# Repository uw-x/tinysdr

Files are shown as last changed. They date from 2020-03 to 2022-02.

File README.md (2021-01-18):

## Overview
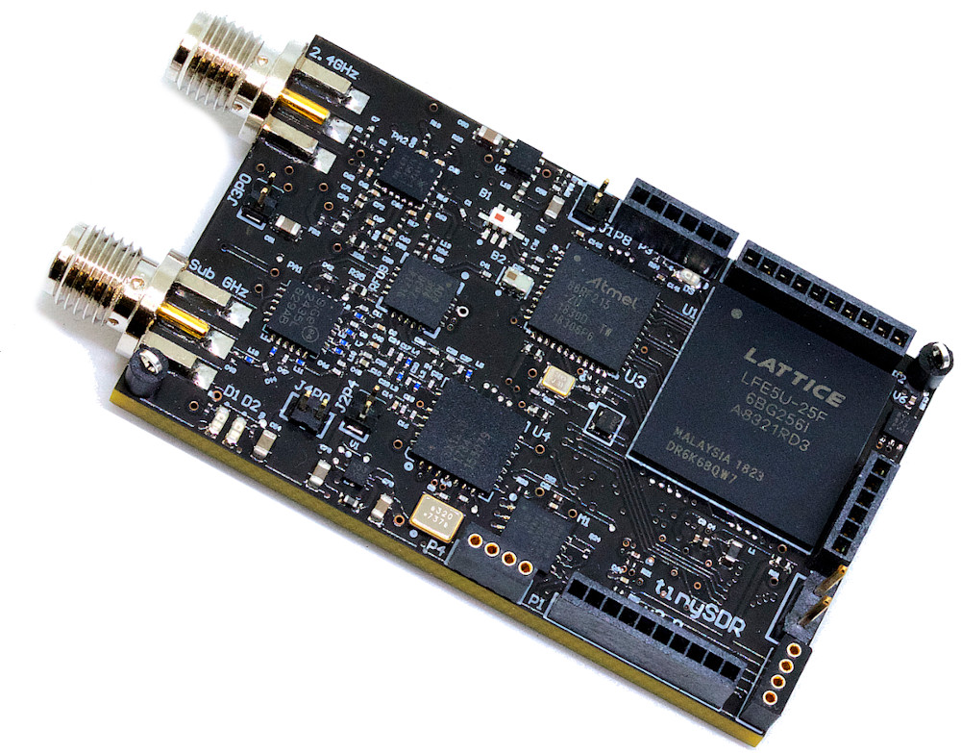
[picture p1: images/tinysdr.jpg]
TinySDR Board


TinySDR is the first software-defined radio platform specialized for internet-of-things networks.

### Hardware
TinySDR schematic is in [hardware](hardware/schematic.pdf). You can download [PCB design files](hardware/pcb-tinysdr.zip) to build TinySDR hardware.

### Firmware
TinySDR firmware CCS project is in [firmware](firmware/).

### FPGA Demos
TinySDR Bluetooth beacons and LoRa demos are in [demo](demo/).
- [LoRa Modulator](https://github.com/uw-x/lora-modulator)
- [FSK Modulator](https://github.com/mehrdadh/fsk-modulator)

### Contributers
  - [Mehrdad Hessar](https://github.com/mehrdadh)
  - [Ali Najafi](https://github.com/anajafi)
  - [Vikram Iyer](https://github.com/viyer)

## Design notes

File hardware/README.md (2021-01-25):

# Overview
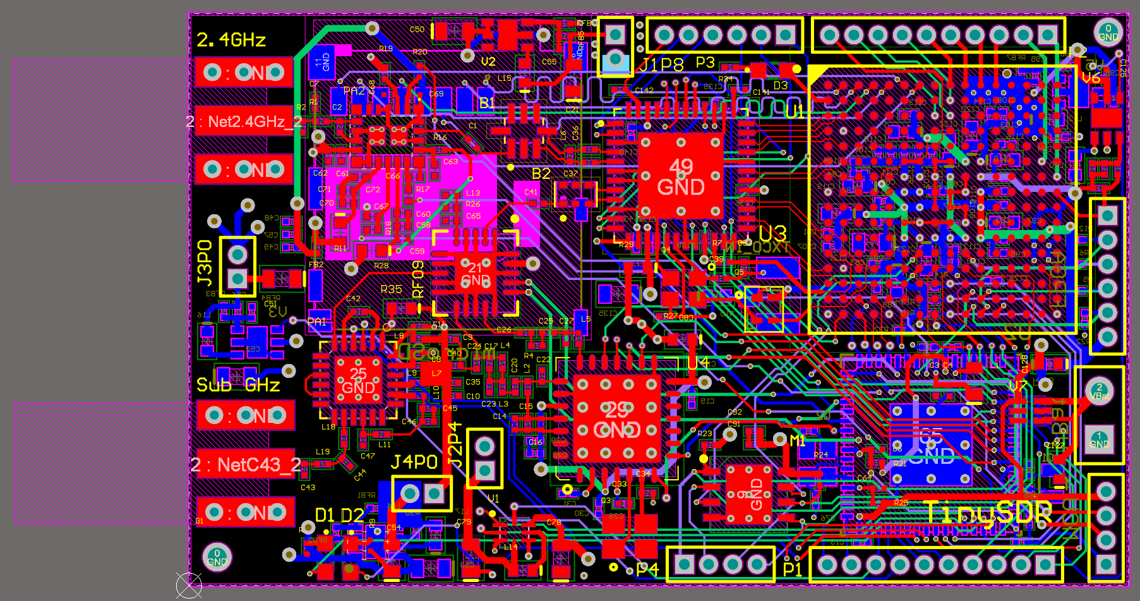
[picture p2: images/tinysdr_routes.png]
TinySDR PCB All Layers


TinySDR hardware designed with a six layers FR4 PCB material. We need six layer to implement multiple components with complex power plains that gives us flexibility to control power consumption in various scenarios.

We place RF paths on the top layer with impedance control for Sub-GHz and 2.4 GHz frequencies.

This PCB is originally designed with Altium Designer version 19 and most recently rendered by version 20.1.11. All the libraries that required to build the PCB are included in [PCB files](./pcb-tinysdr.zip).

## Layers
After routing wires for all components we place polygons on each layer. In table below we show all the polygons and their purpose in our design.

| Layer | Polygons Description |Image  |
| --- | --- |---|
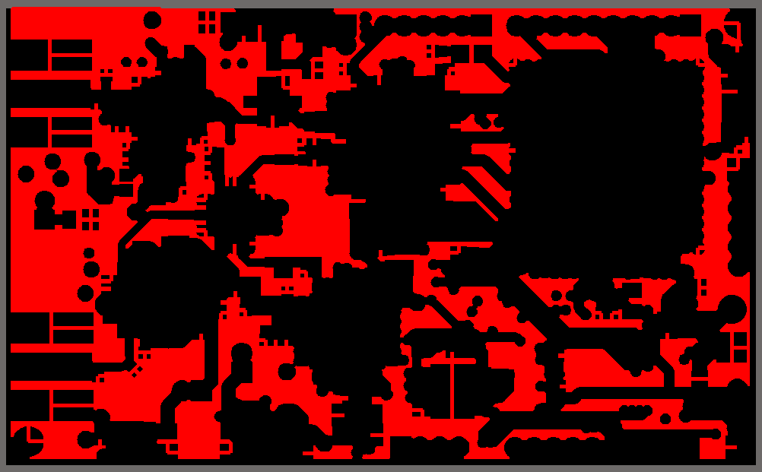
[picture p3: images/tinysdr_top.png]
Top Layer Polygon
| Top | Connected to GND.<br /> Multiple Polygons.<br /> Includes impedance control for both RF paths and LVDS connections. | |
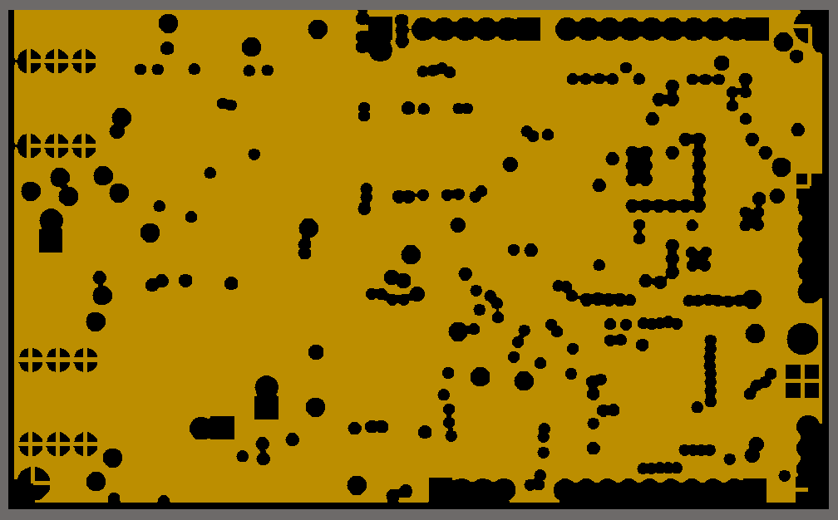
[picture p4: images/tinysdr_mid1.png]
Inner Layer 1 Polygon
| Inner 1 | Connected to GND. | |
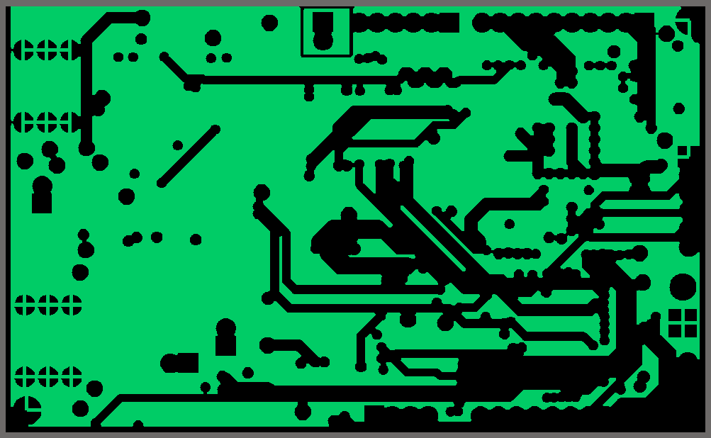
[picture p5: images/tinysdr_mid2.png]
Inner Layer 2 Polygon
| Inner 2 | Connected to GND. | |
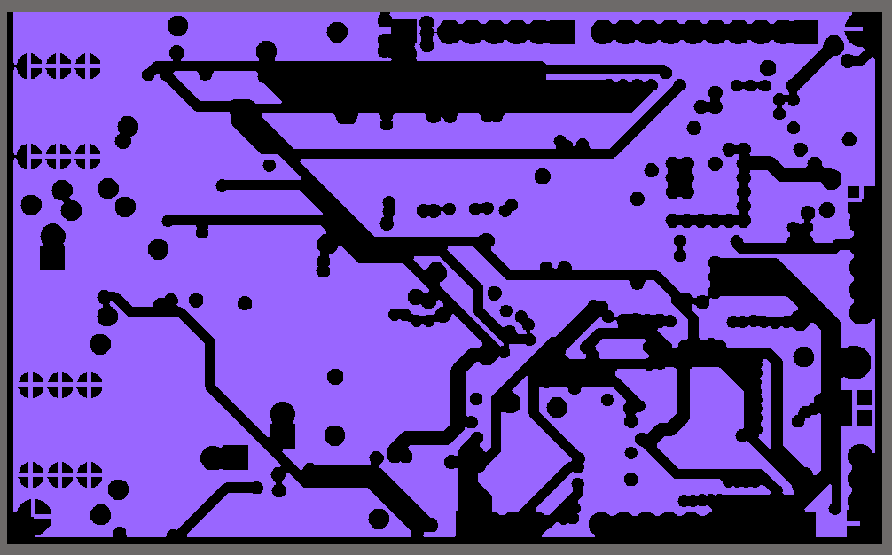
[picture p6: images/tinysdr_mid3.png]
Inner Layer 3 Polygon
| Inner 3 | Connected to GND. | |
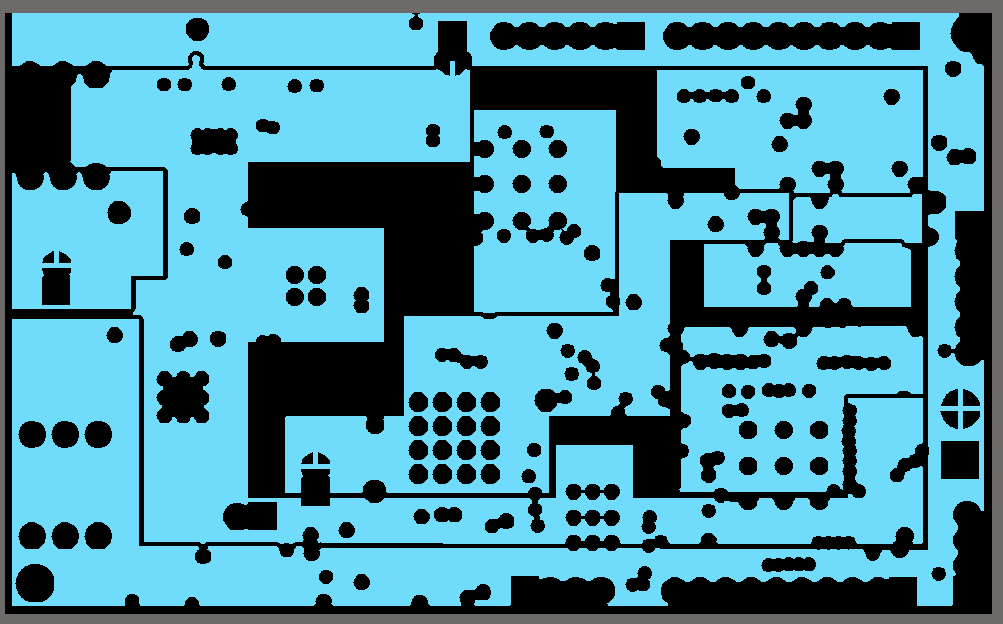
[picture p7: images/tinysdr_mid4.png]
Inner Layer 4 Polygons
| Inner 4 | Connected to Power.<br /> Includes multiple polygons for various power planes. | |
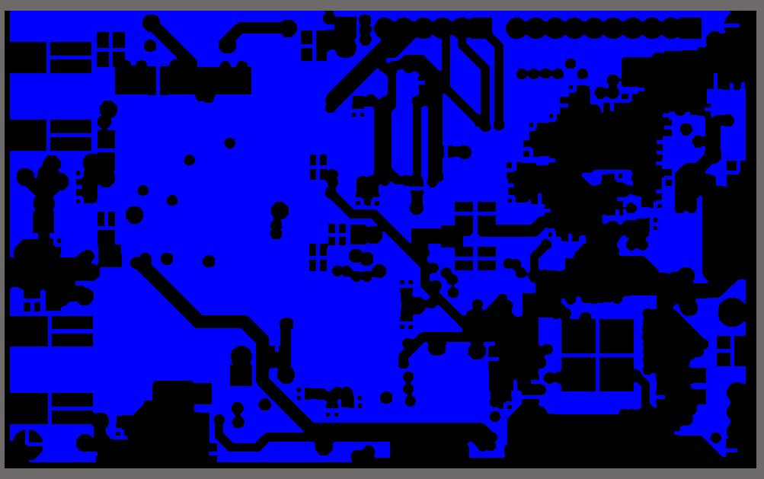
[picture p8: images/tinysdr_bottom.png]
Bottom Layer Polygon
| Bottom | Connected to GND. | |

## How to Use
To use PCB files in this directory follow these steps:
- Install the latest version of the [Altium Designer](https://www.altium.com/products/downloads)
- Download and extract [PCB files](./pcb-tinysdr.zip)
- Open project in Altium Designer

Note: When you run design rule check you will see few erros regarding the `silk gaps` which you can ignore.

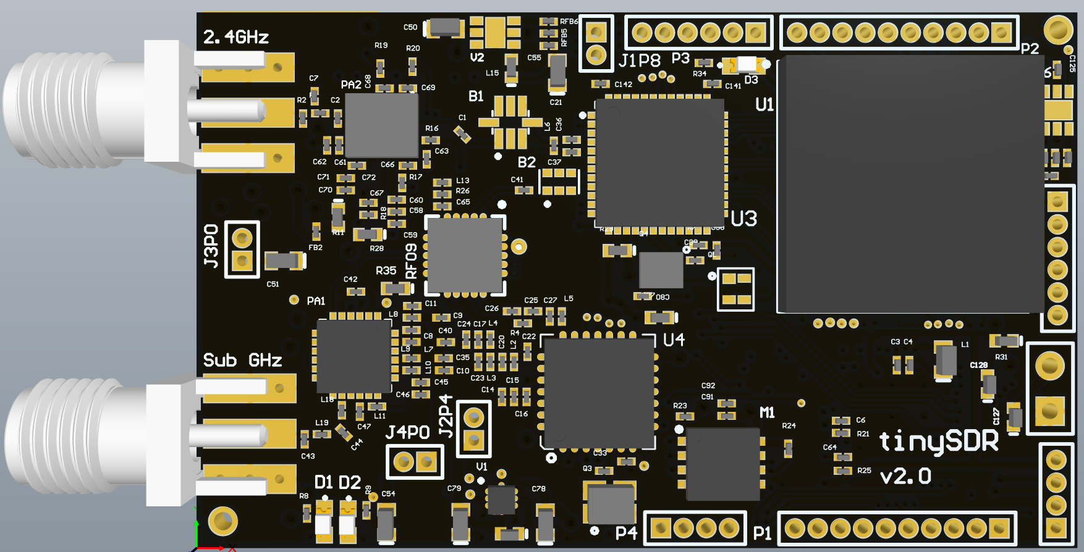
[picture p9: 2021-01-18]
images/tinysdr_3d.png

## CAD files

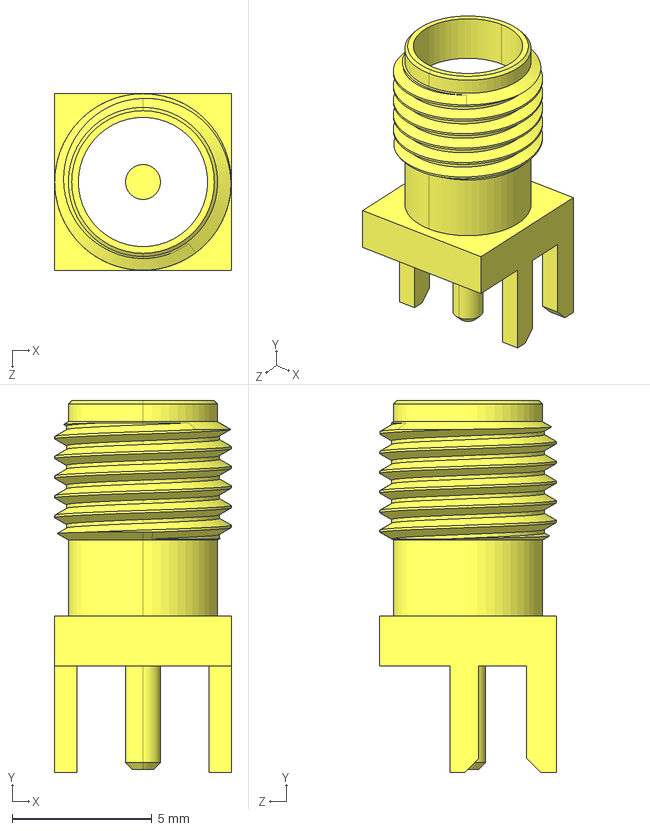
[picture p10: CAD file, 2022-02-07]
hardware/pcb-tinysdr/ALTIUM_EMBEDDED_MODELS/Samtec-SMA-J-P-H-ST-EM1.step
6.35 x 13.3 x 6.35 mm

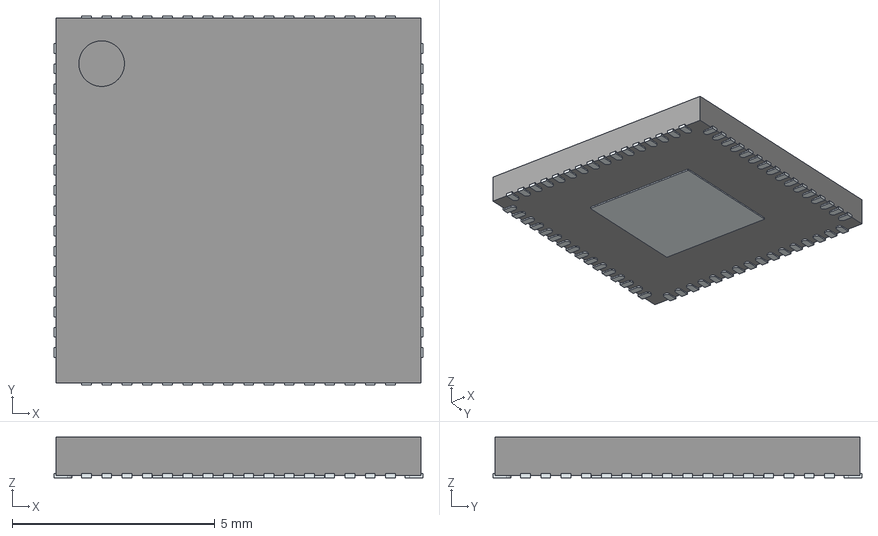
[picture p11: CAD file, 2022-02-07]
hardware/pcb-tinysdr/ALTIUM_EMBEDDED_MODELS/MSP432P401RIRGCR.stp
9.10 x 9.10 x 1.00 mm
ThermalPin
PinsArrayLR
PinsArrayTB

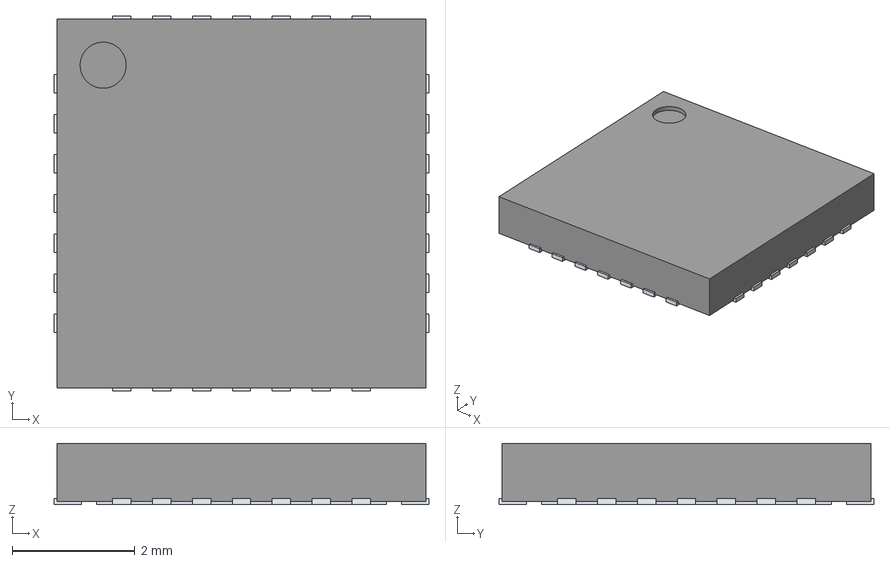
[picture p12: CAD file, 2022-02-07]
hardware/pcb-tinysdr/ALTIUM_EMBEDDED_MODELS/SX1276IMLTRT.stp
6.10 x 6.10 x 1.00 mm
ThermalPin
PinsArrayLR
PinsArrayTB

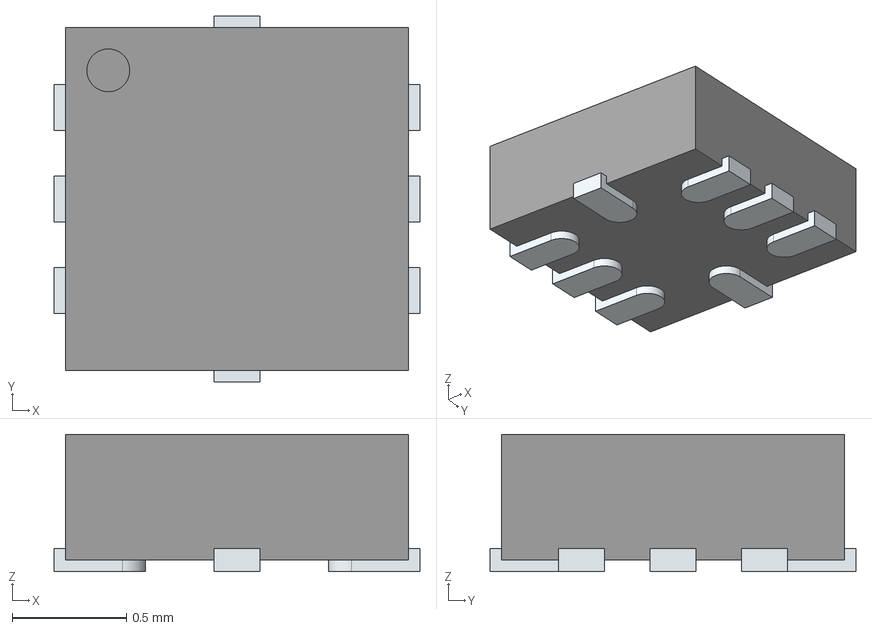
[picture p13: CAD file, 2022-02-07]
hardware/pcb-tinysdr/ALTIUM_EMBEDDED_MODELS/SC560HULTRT.stp
1.60 x 1.60 x 0.6 mm
PinsArrayLR
PinsArrayTB

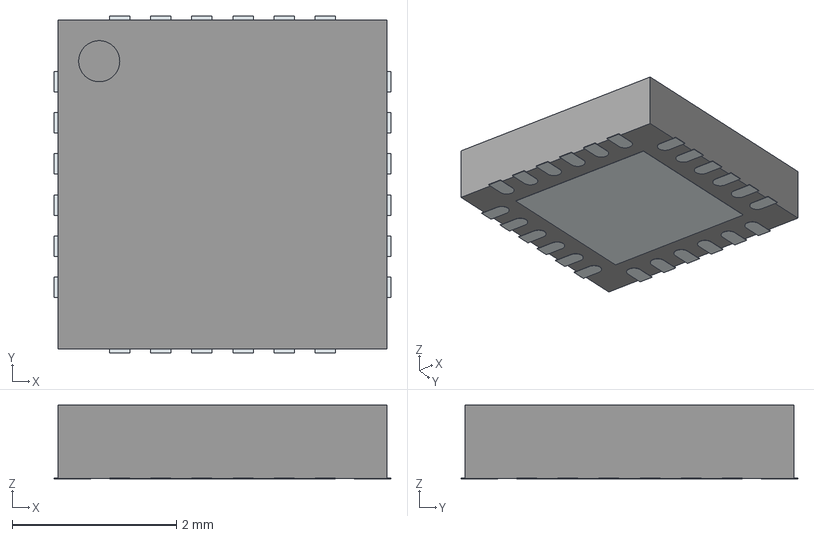
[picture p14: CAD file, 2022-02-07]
hardware/pcb-tinysdr/ALTIUM_EMBEDDED_MODELS/SE2435L-R.stp
4.10 x 4.10 x 0.9 mm
ThermalPin
PinsArrayLR
PinsArrayTB

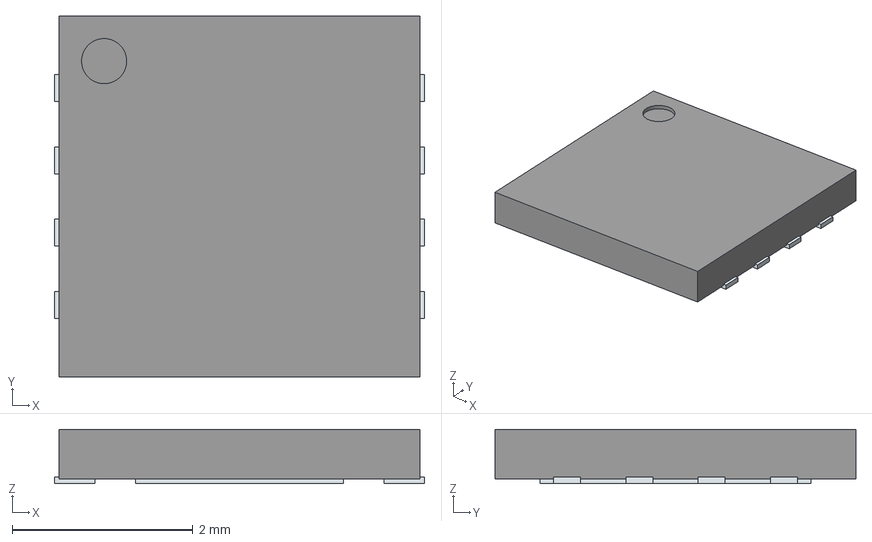
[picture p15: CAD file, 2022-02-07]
hardware/pcb-tinysdr/ALTIUM_EMBEDDED_MODELS/S25FL064LABNFI043.stp
4.10 x 4.00 x 0.6 mm
ThermalPin
PinsArrayLR

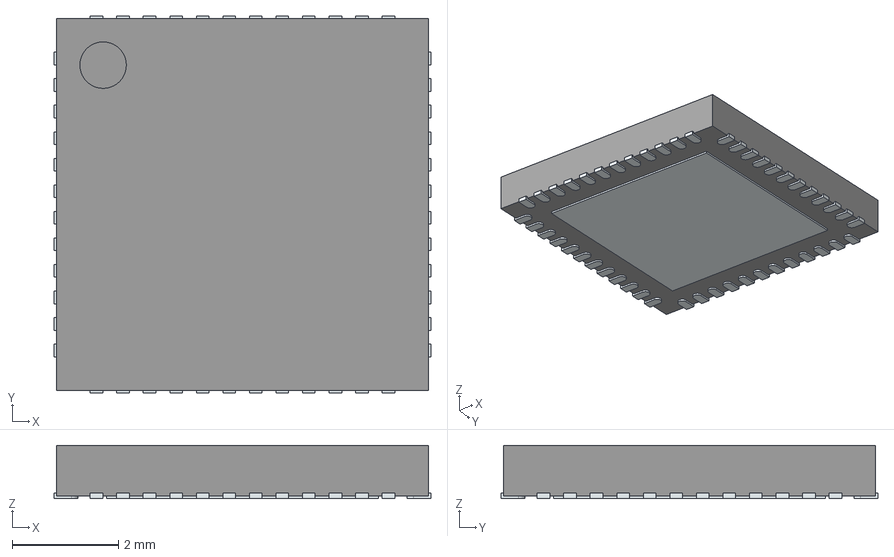
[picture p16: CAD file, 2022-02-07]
hardware/pcb-tinysdr/ALTIUM_EMBEDDED_MODELS/CLT01-38SQ7-TR.stp
7.10 x 7.10 x 1.00 mm
ThermalPin
PinsArrayLR
PinsArrayTB

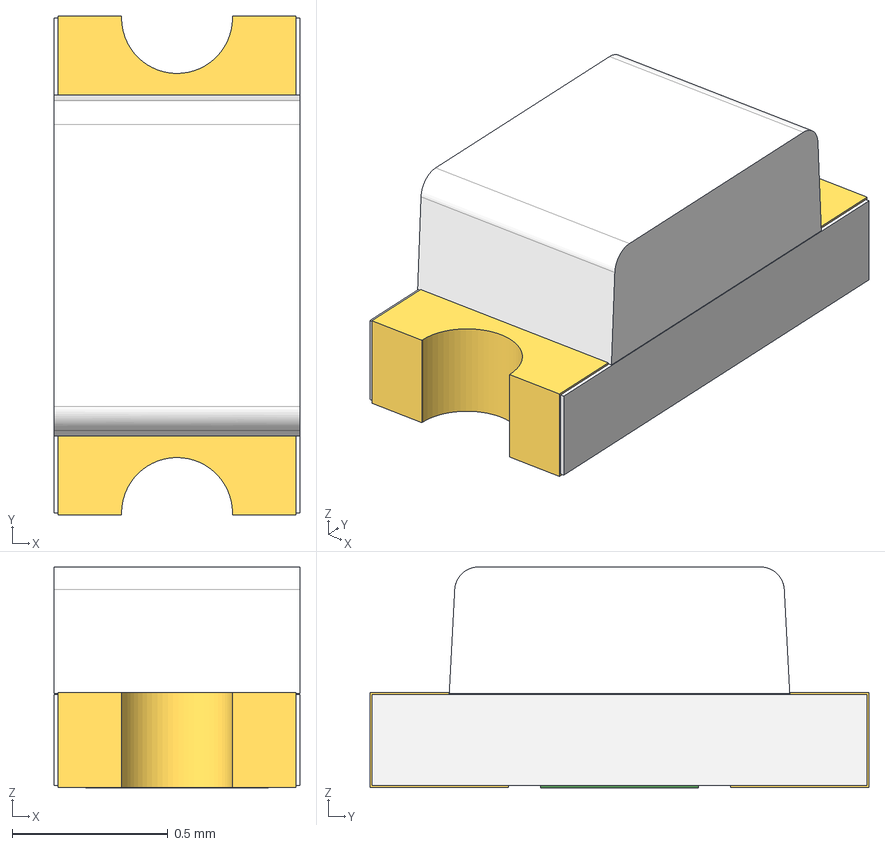
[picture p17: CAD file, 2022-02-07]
hardware/pcb-tinysdr/ALTIUM_EMBEDDED_MODELS/LED 0603 single color.stp
0.787 x 1.60 x 0.709 mm

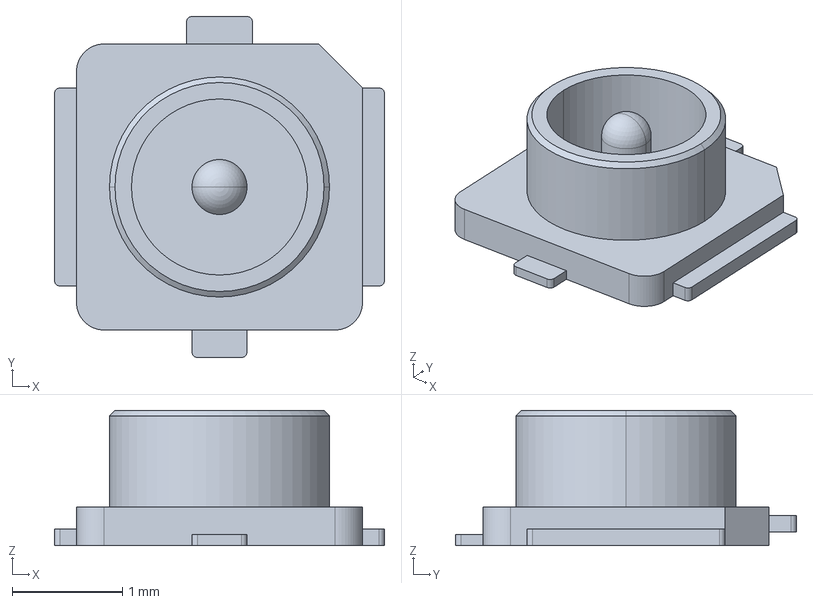
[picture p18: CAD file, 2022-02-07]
hardware/pcb-tinysdr/ALTIUM_EMBEDDED_MODELS/c-1909763-1-b-3d.stp
3.00 x 3.10 x 1.23 mm

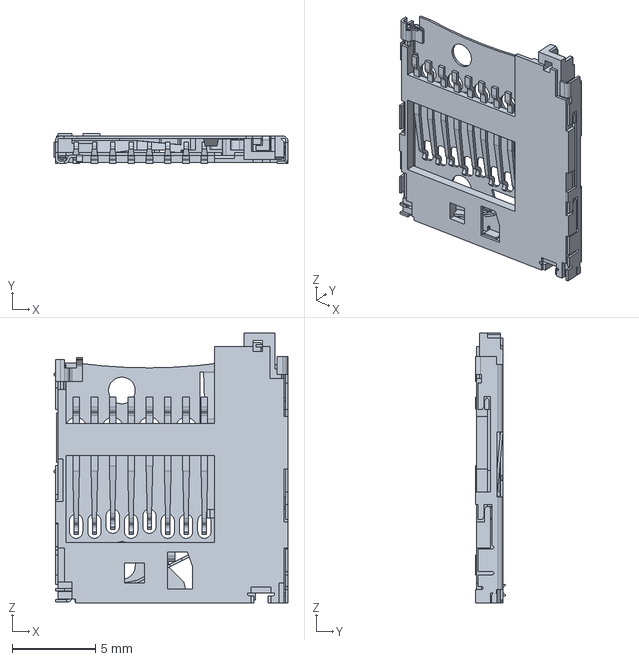
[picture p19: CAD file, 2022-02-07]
hardware/pcb-tinysdr/ALTIUM_EMBEDDED_MODELS/c-2201778-1-a-3d.stp
14.0 x 1.80 x 16.2 mm

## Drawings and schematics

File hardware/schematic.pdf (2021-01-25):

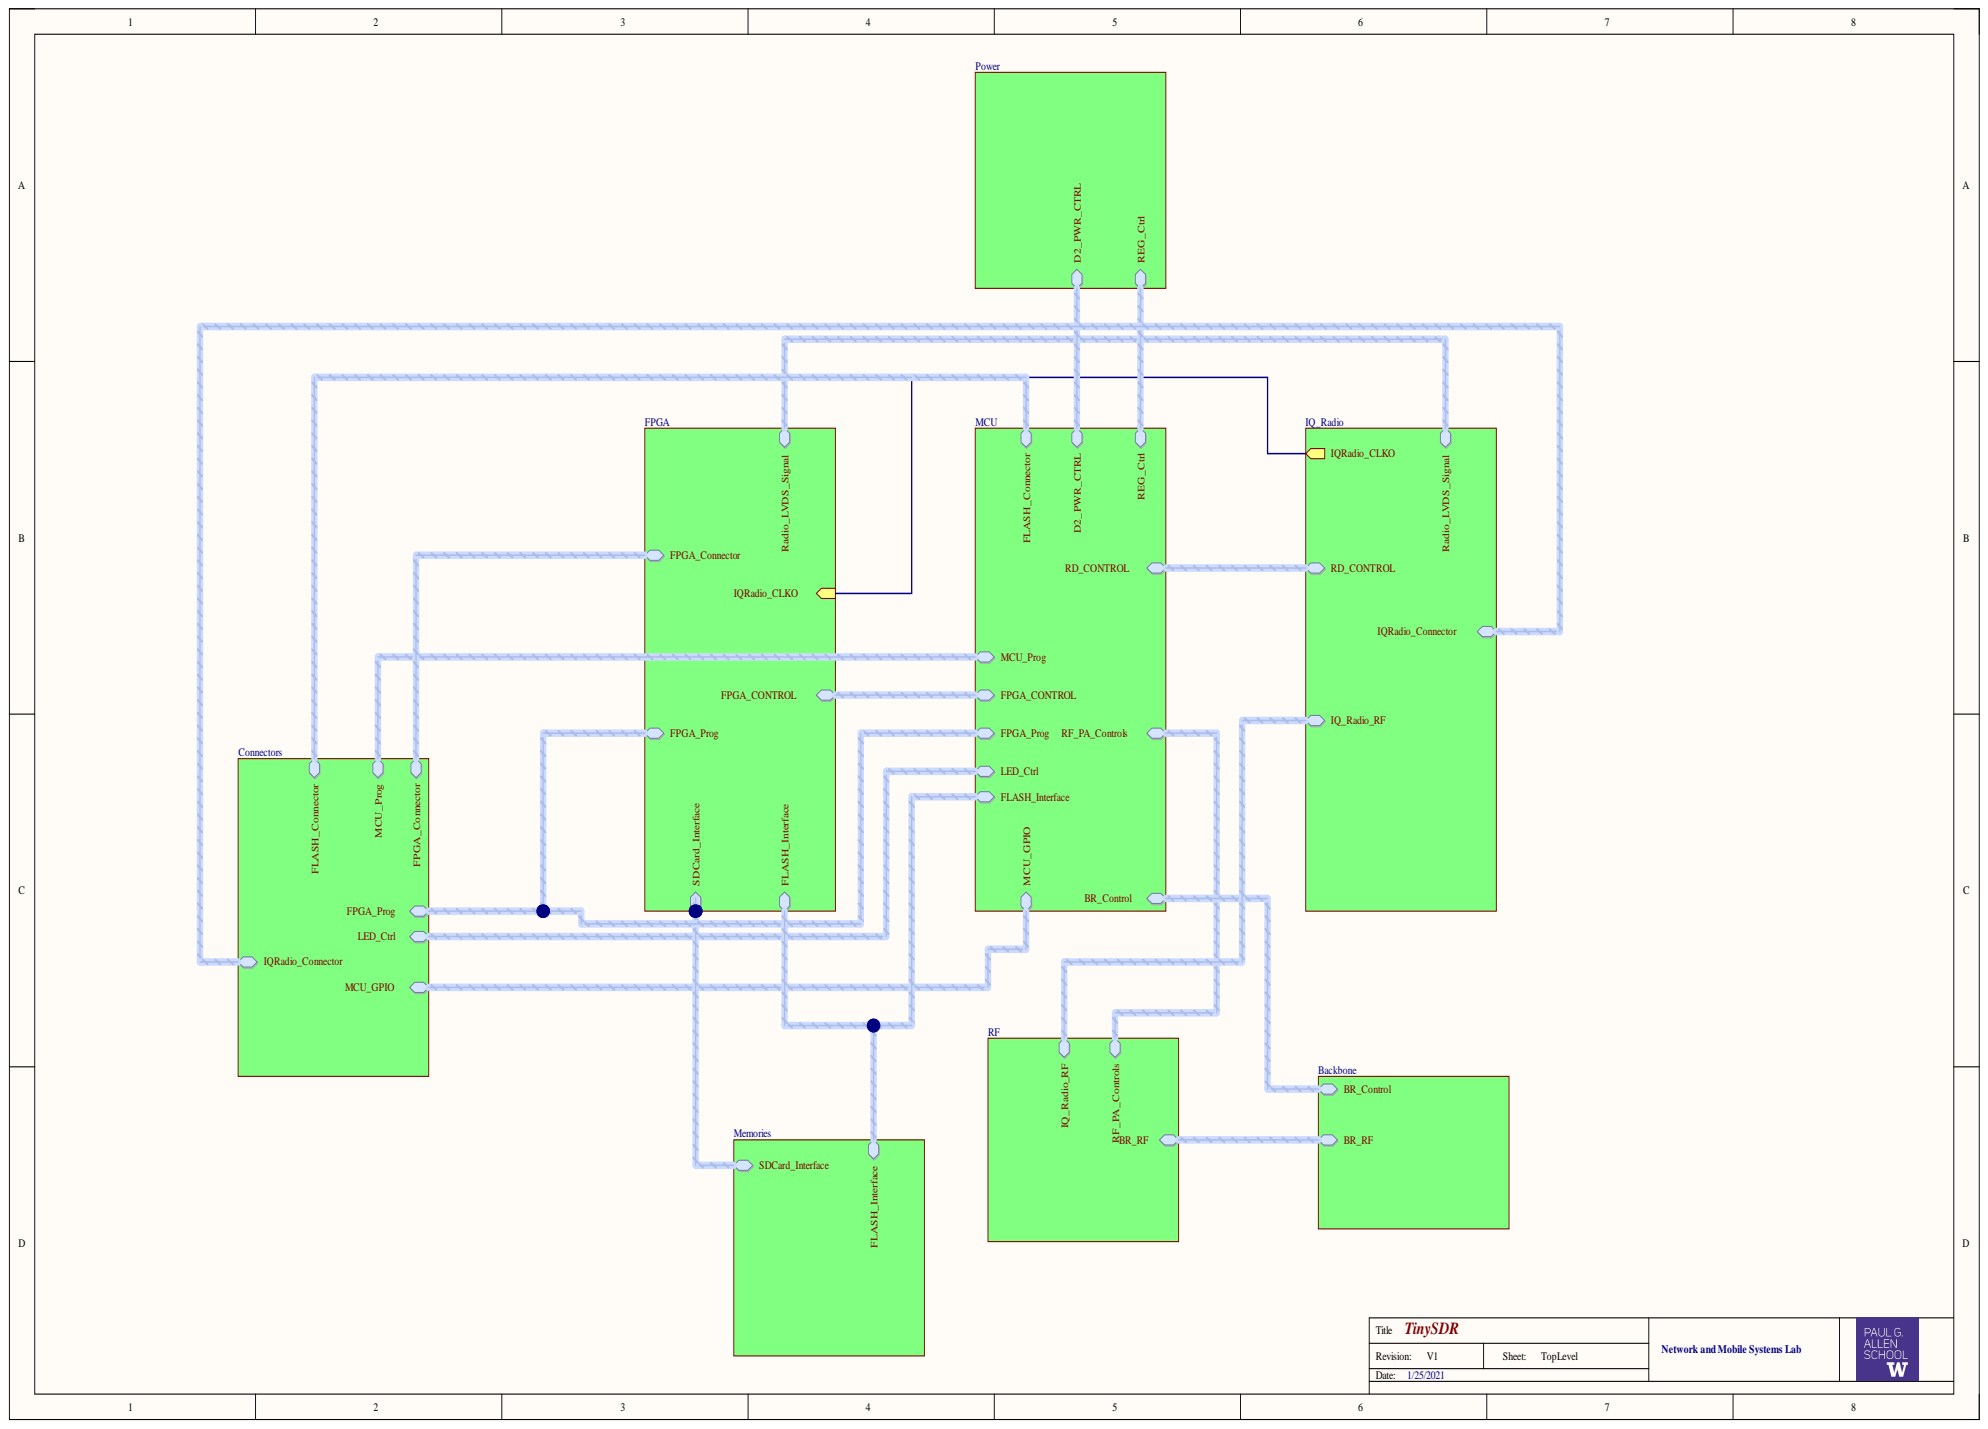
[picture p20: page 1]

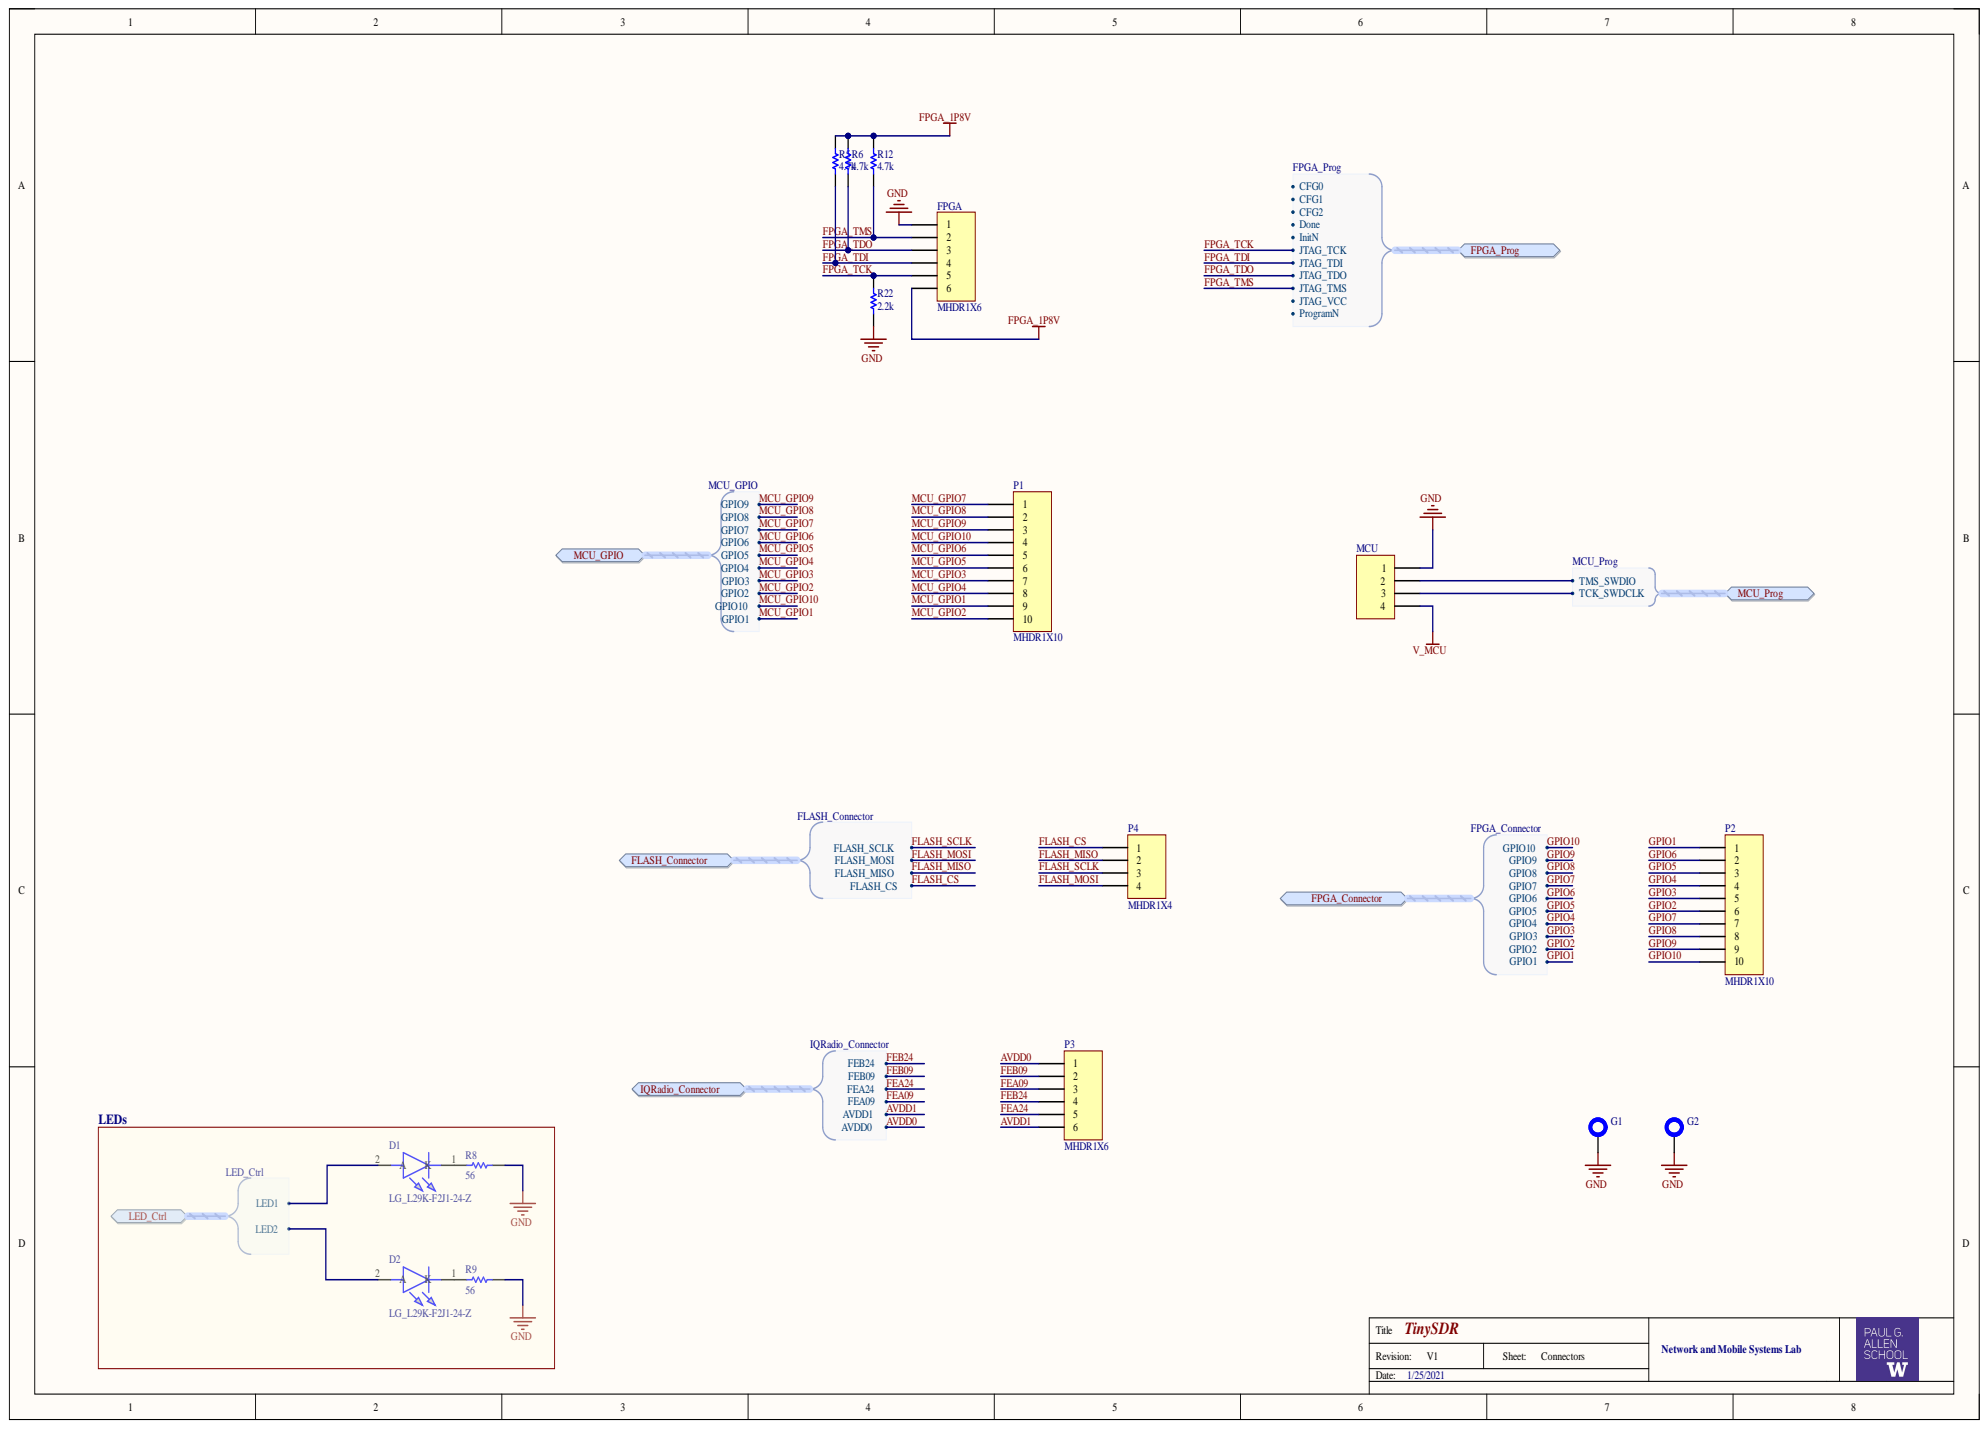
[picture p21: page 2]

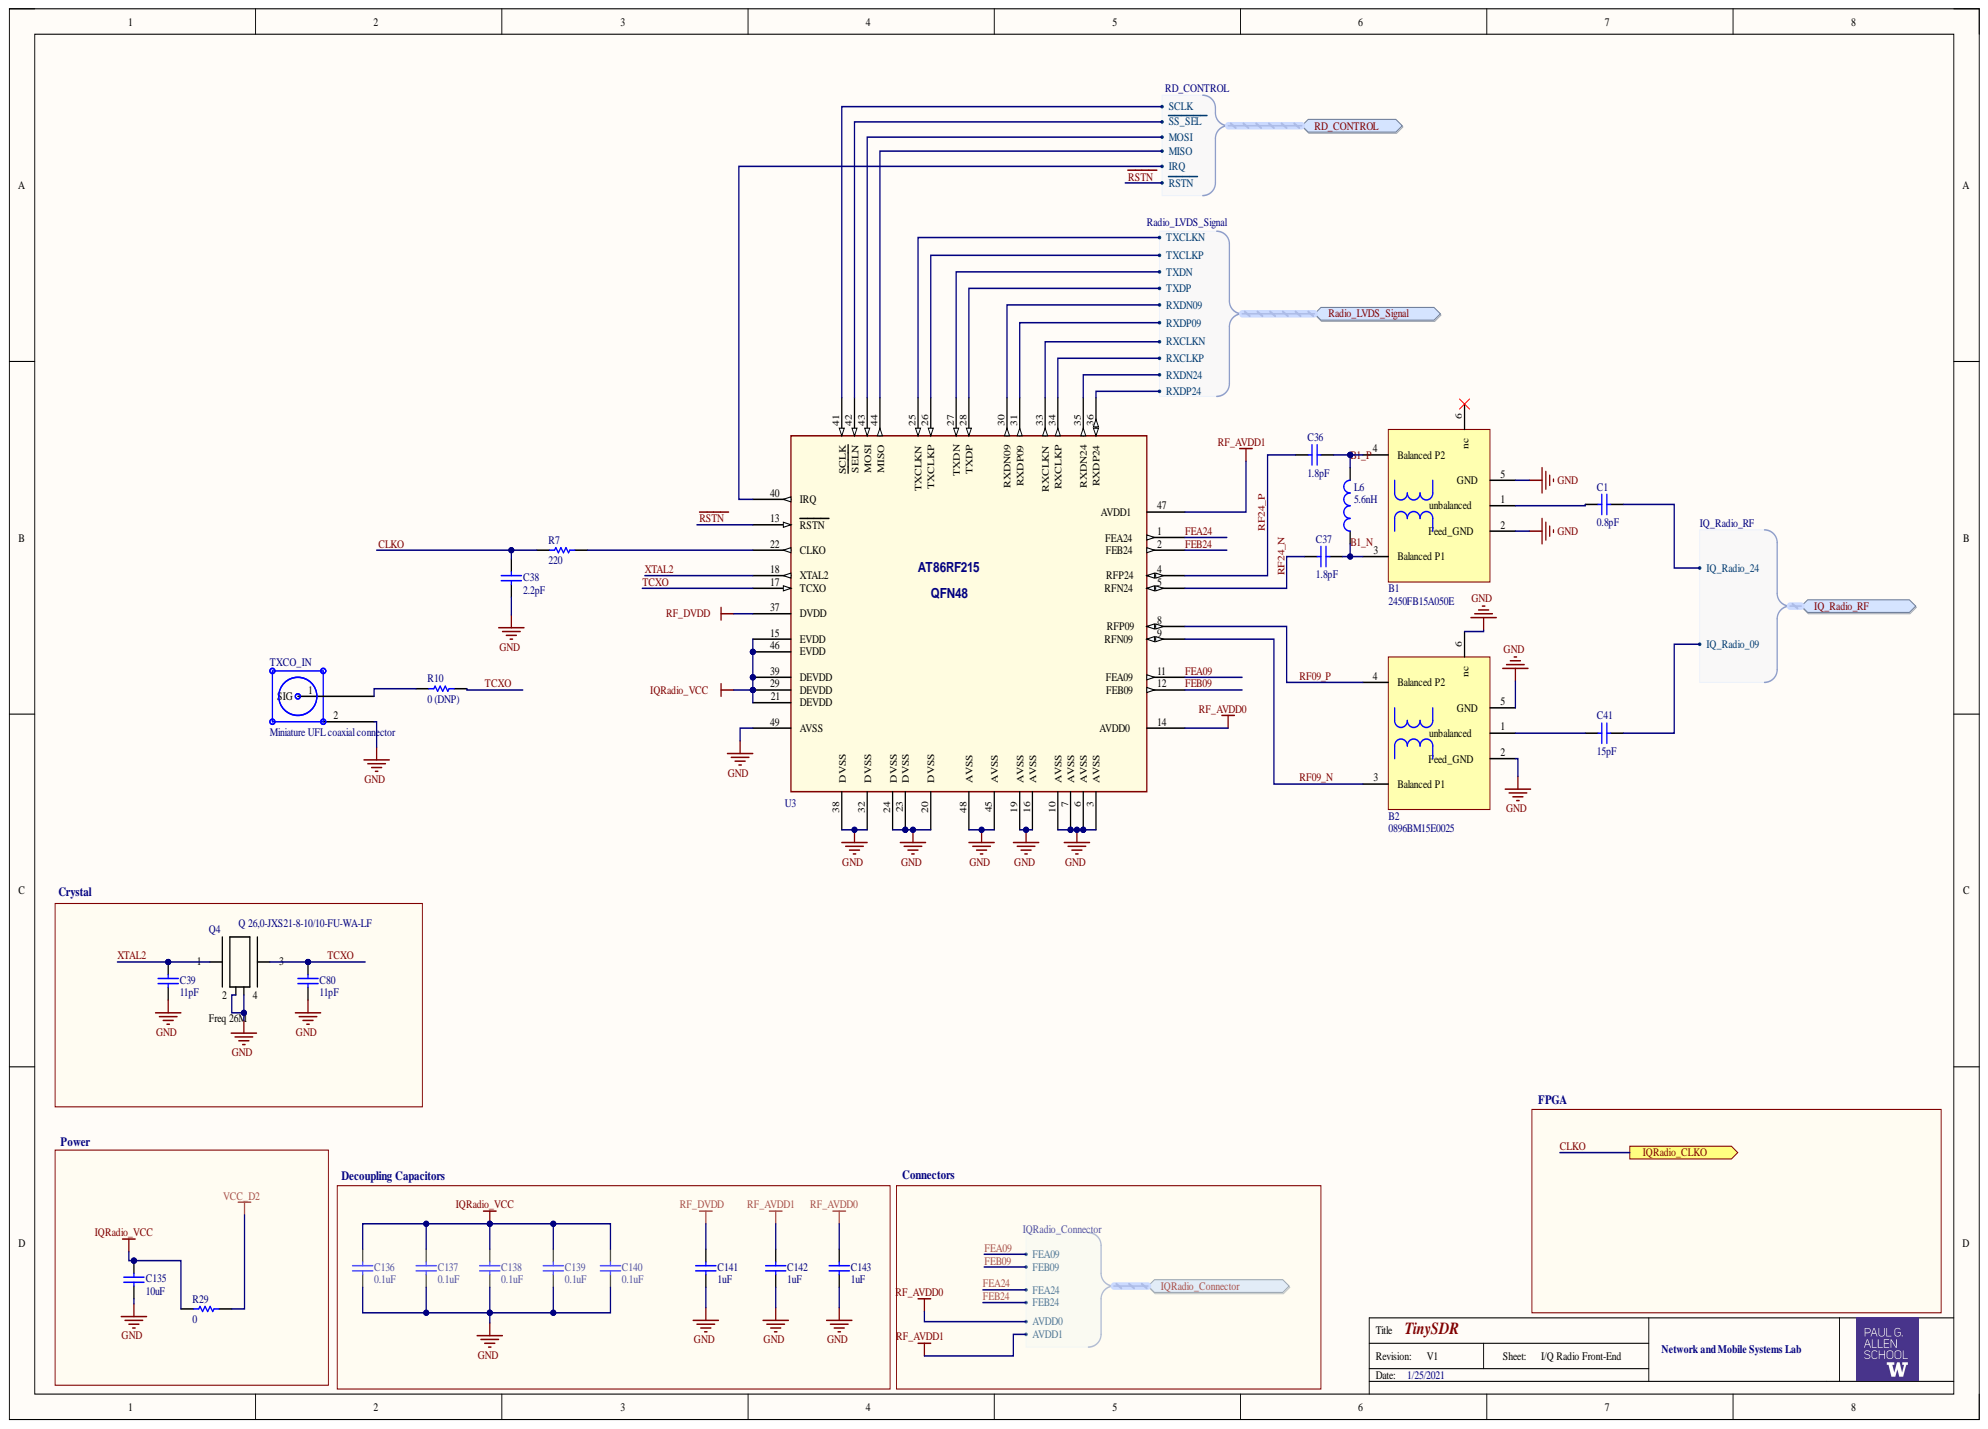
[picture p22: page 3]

Miniature UFL coaxial connector

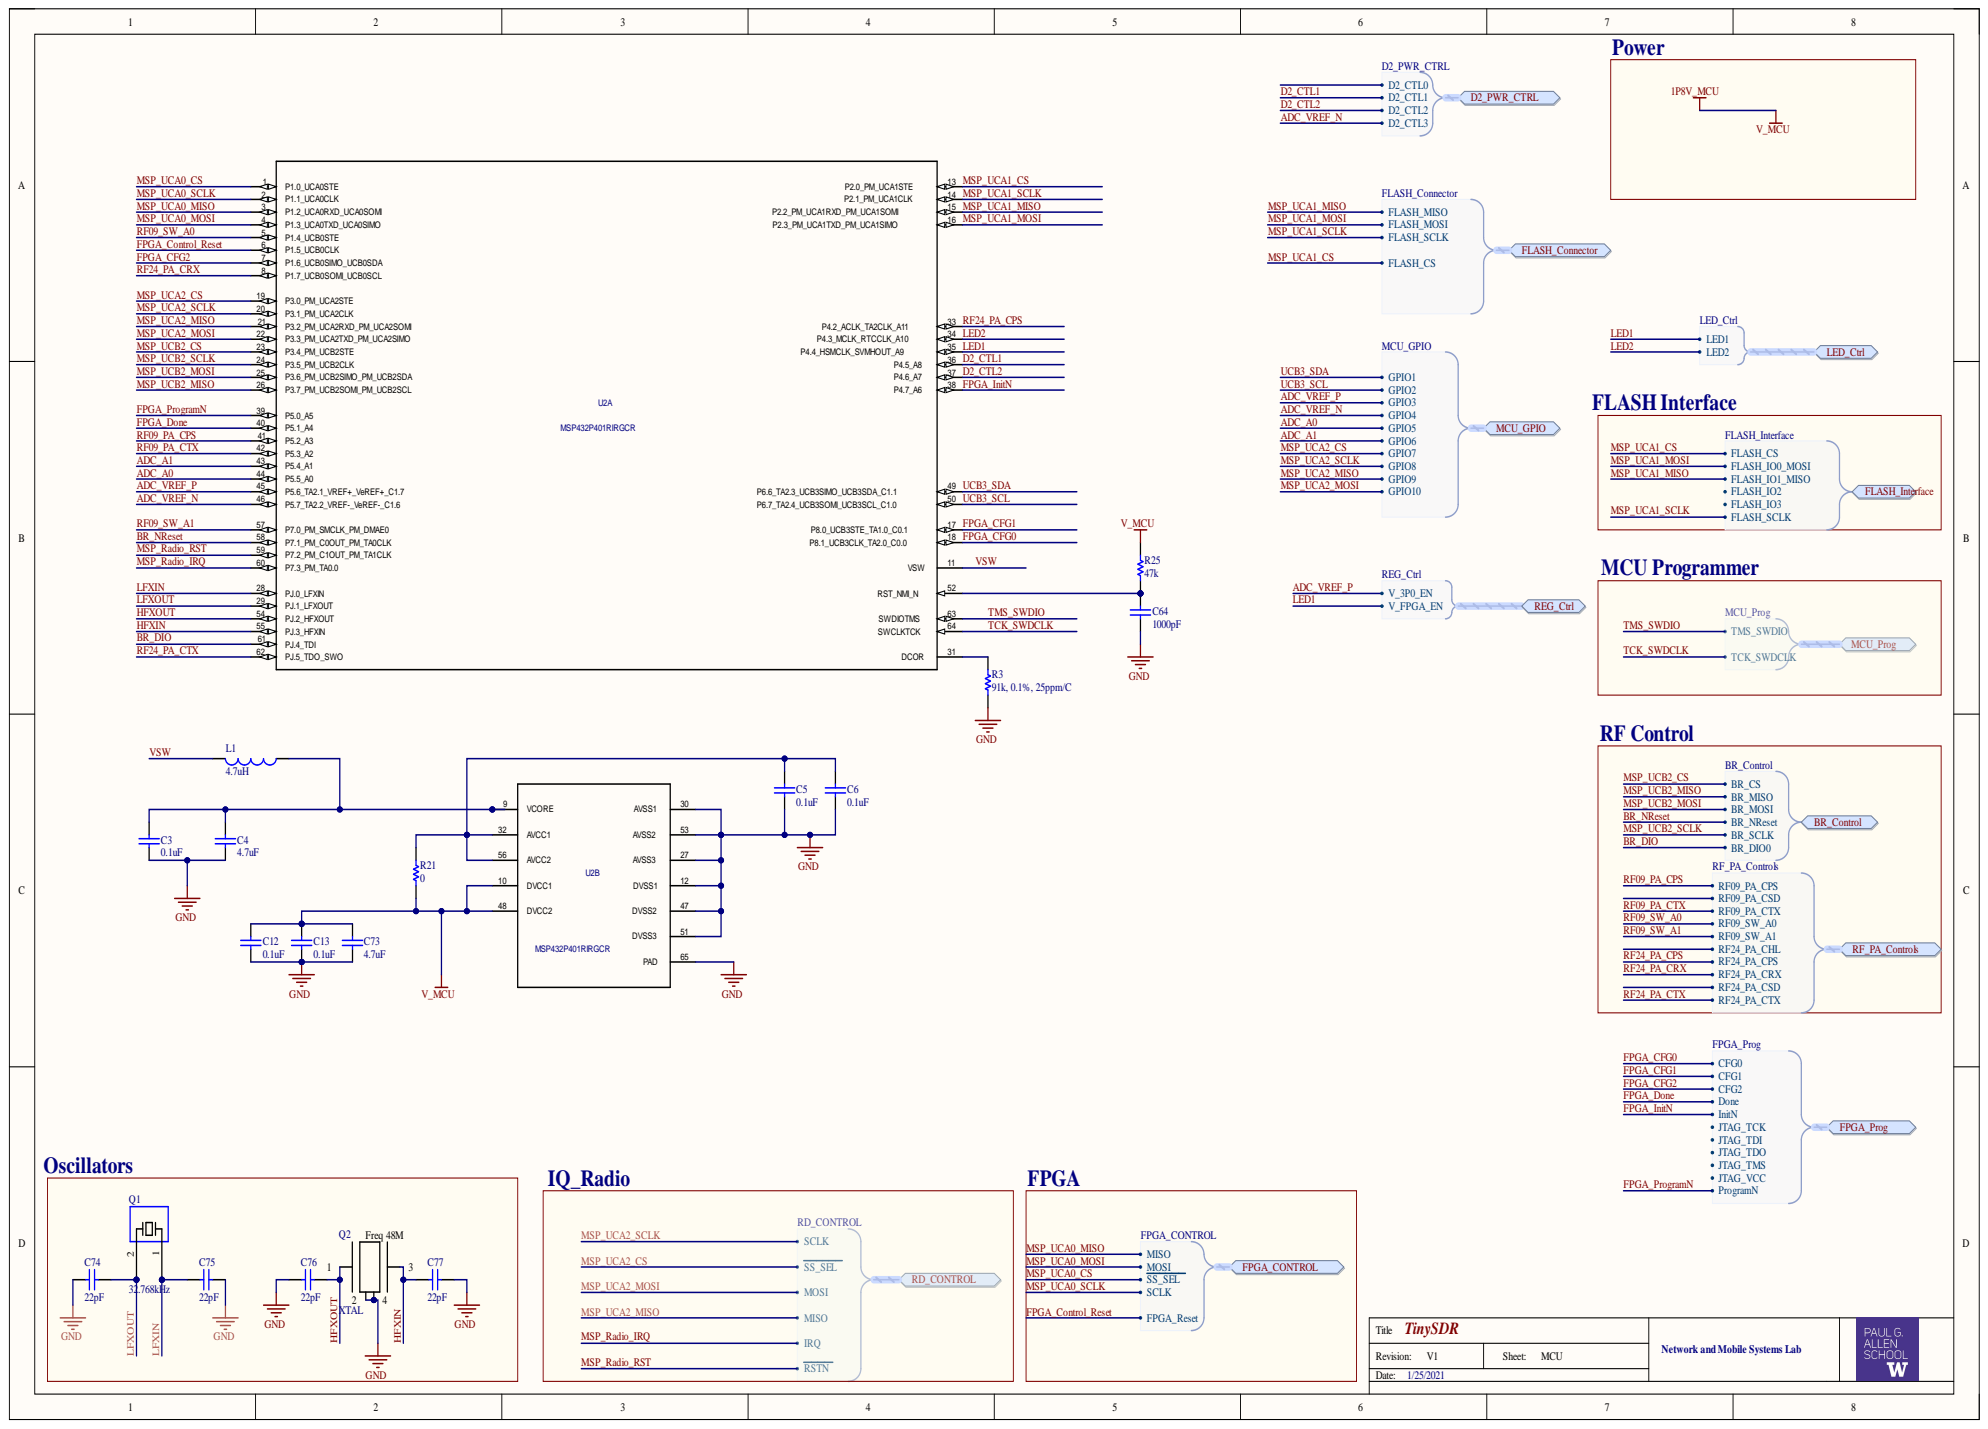
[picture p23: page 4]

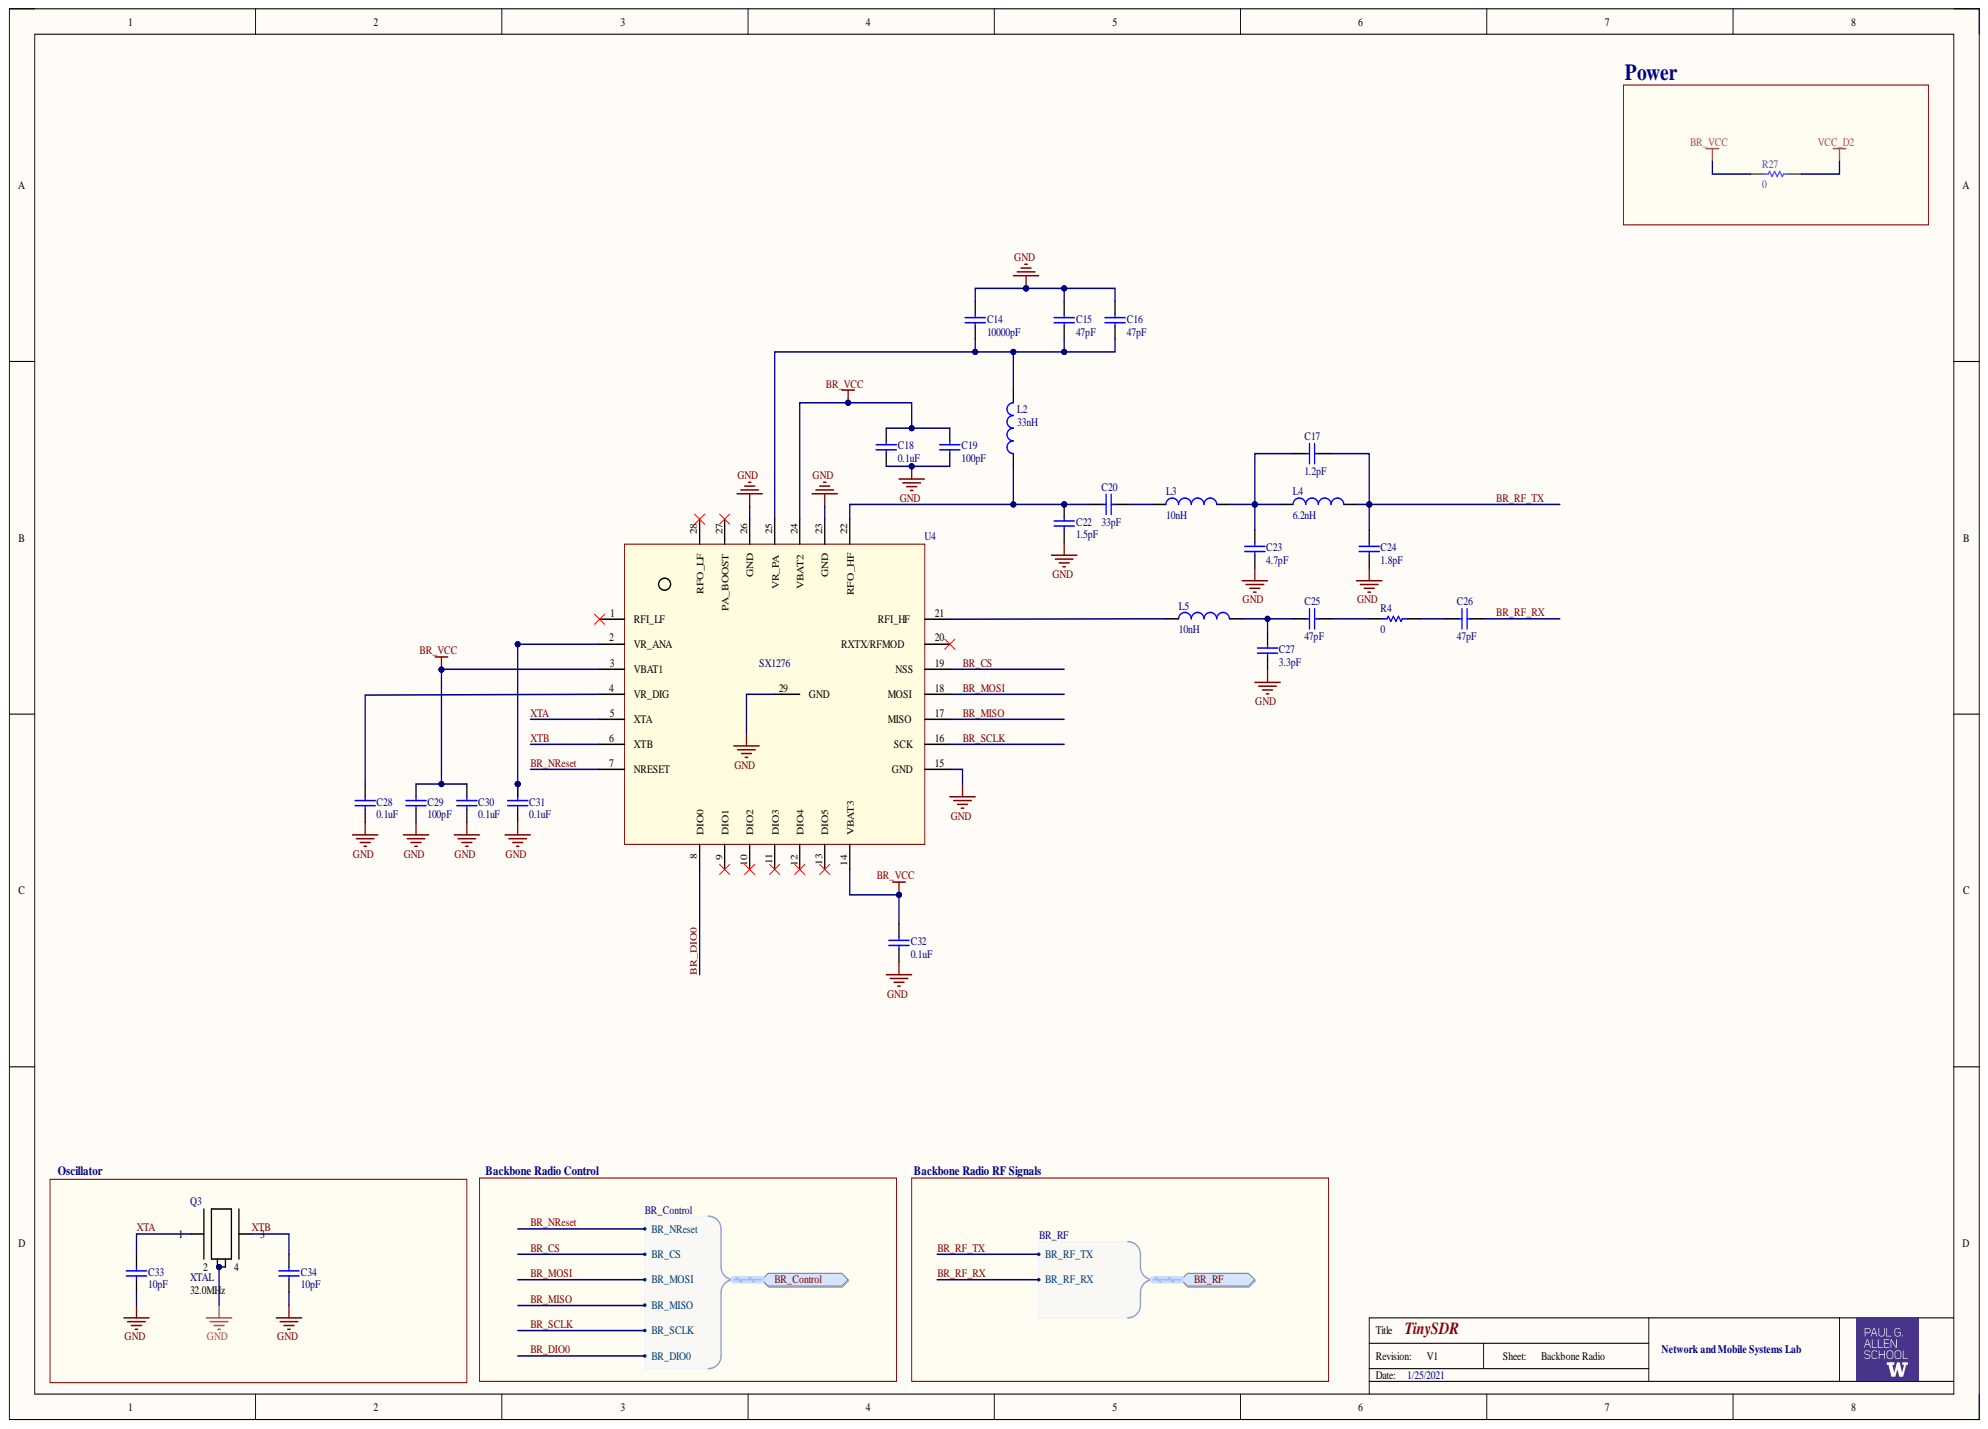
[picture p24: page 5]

VBAT1 3

VR_DIG 4

XTA XTB BR_NReset | | XTA 5 XTB 6 NRESET 7

Backbone Radio RF Signals

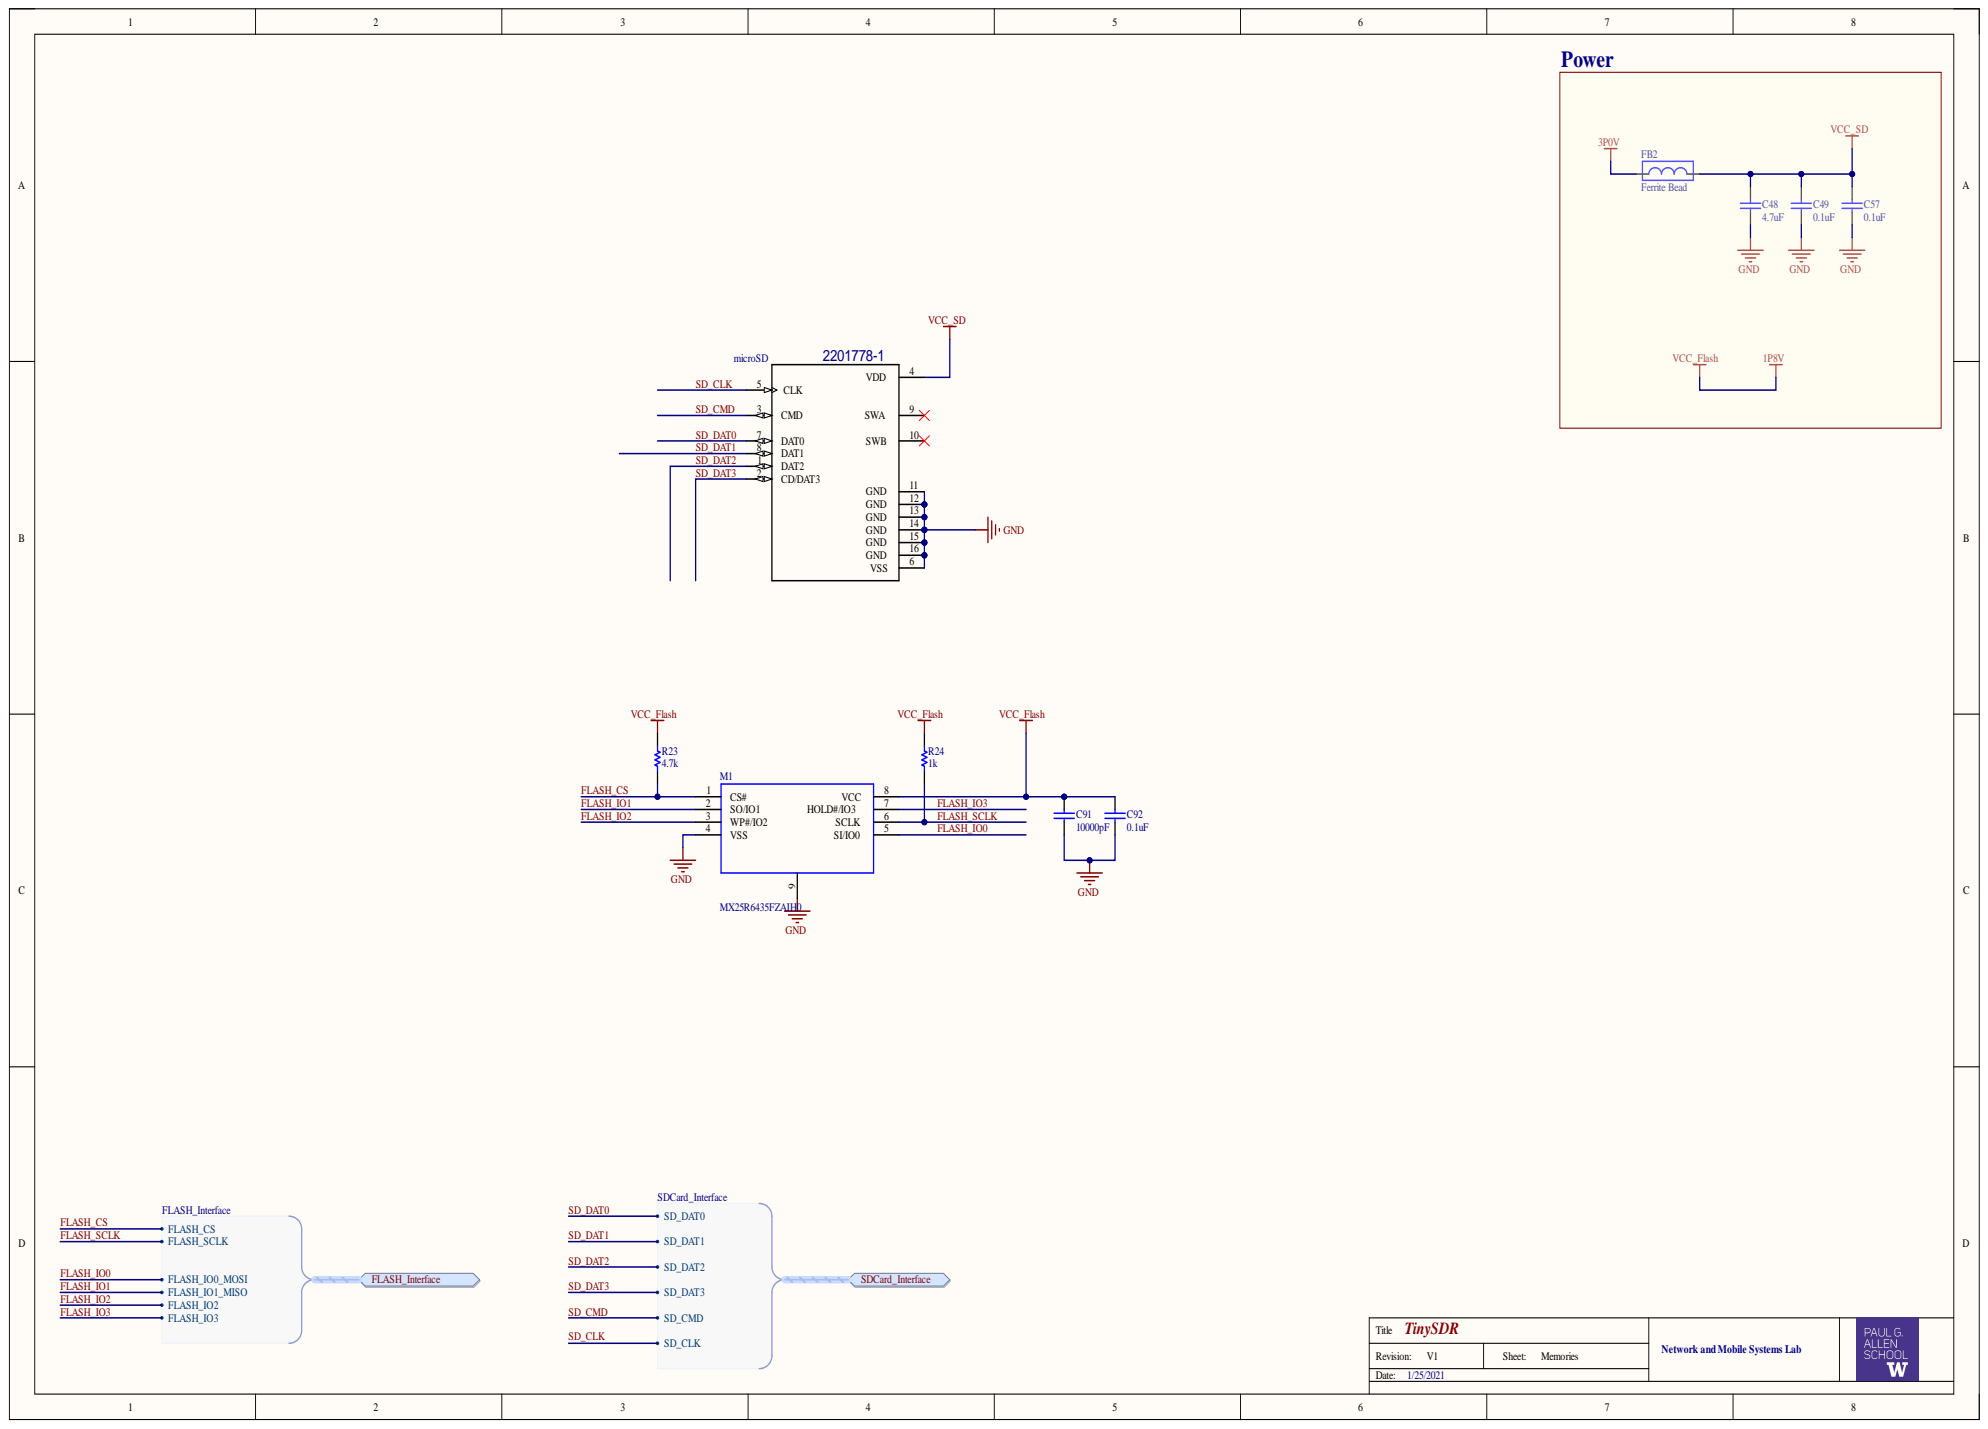
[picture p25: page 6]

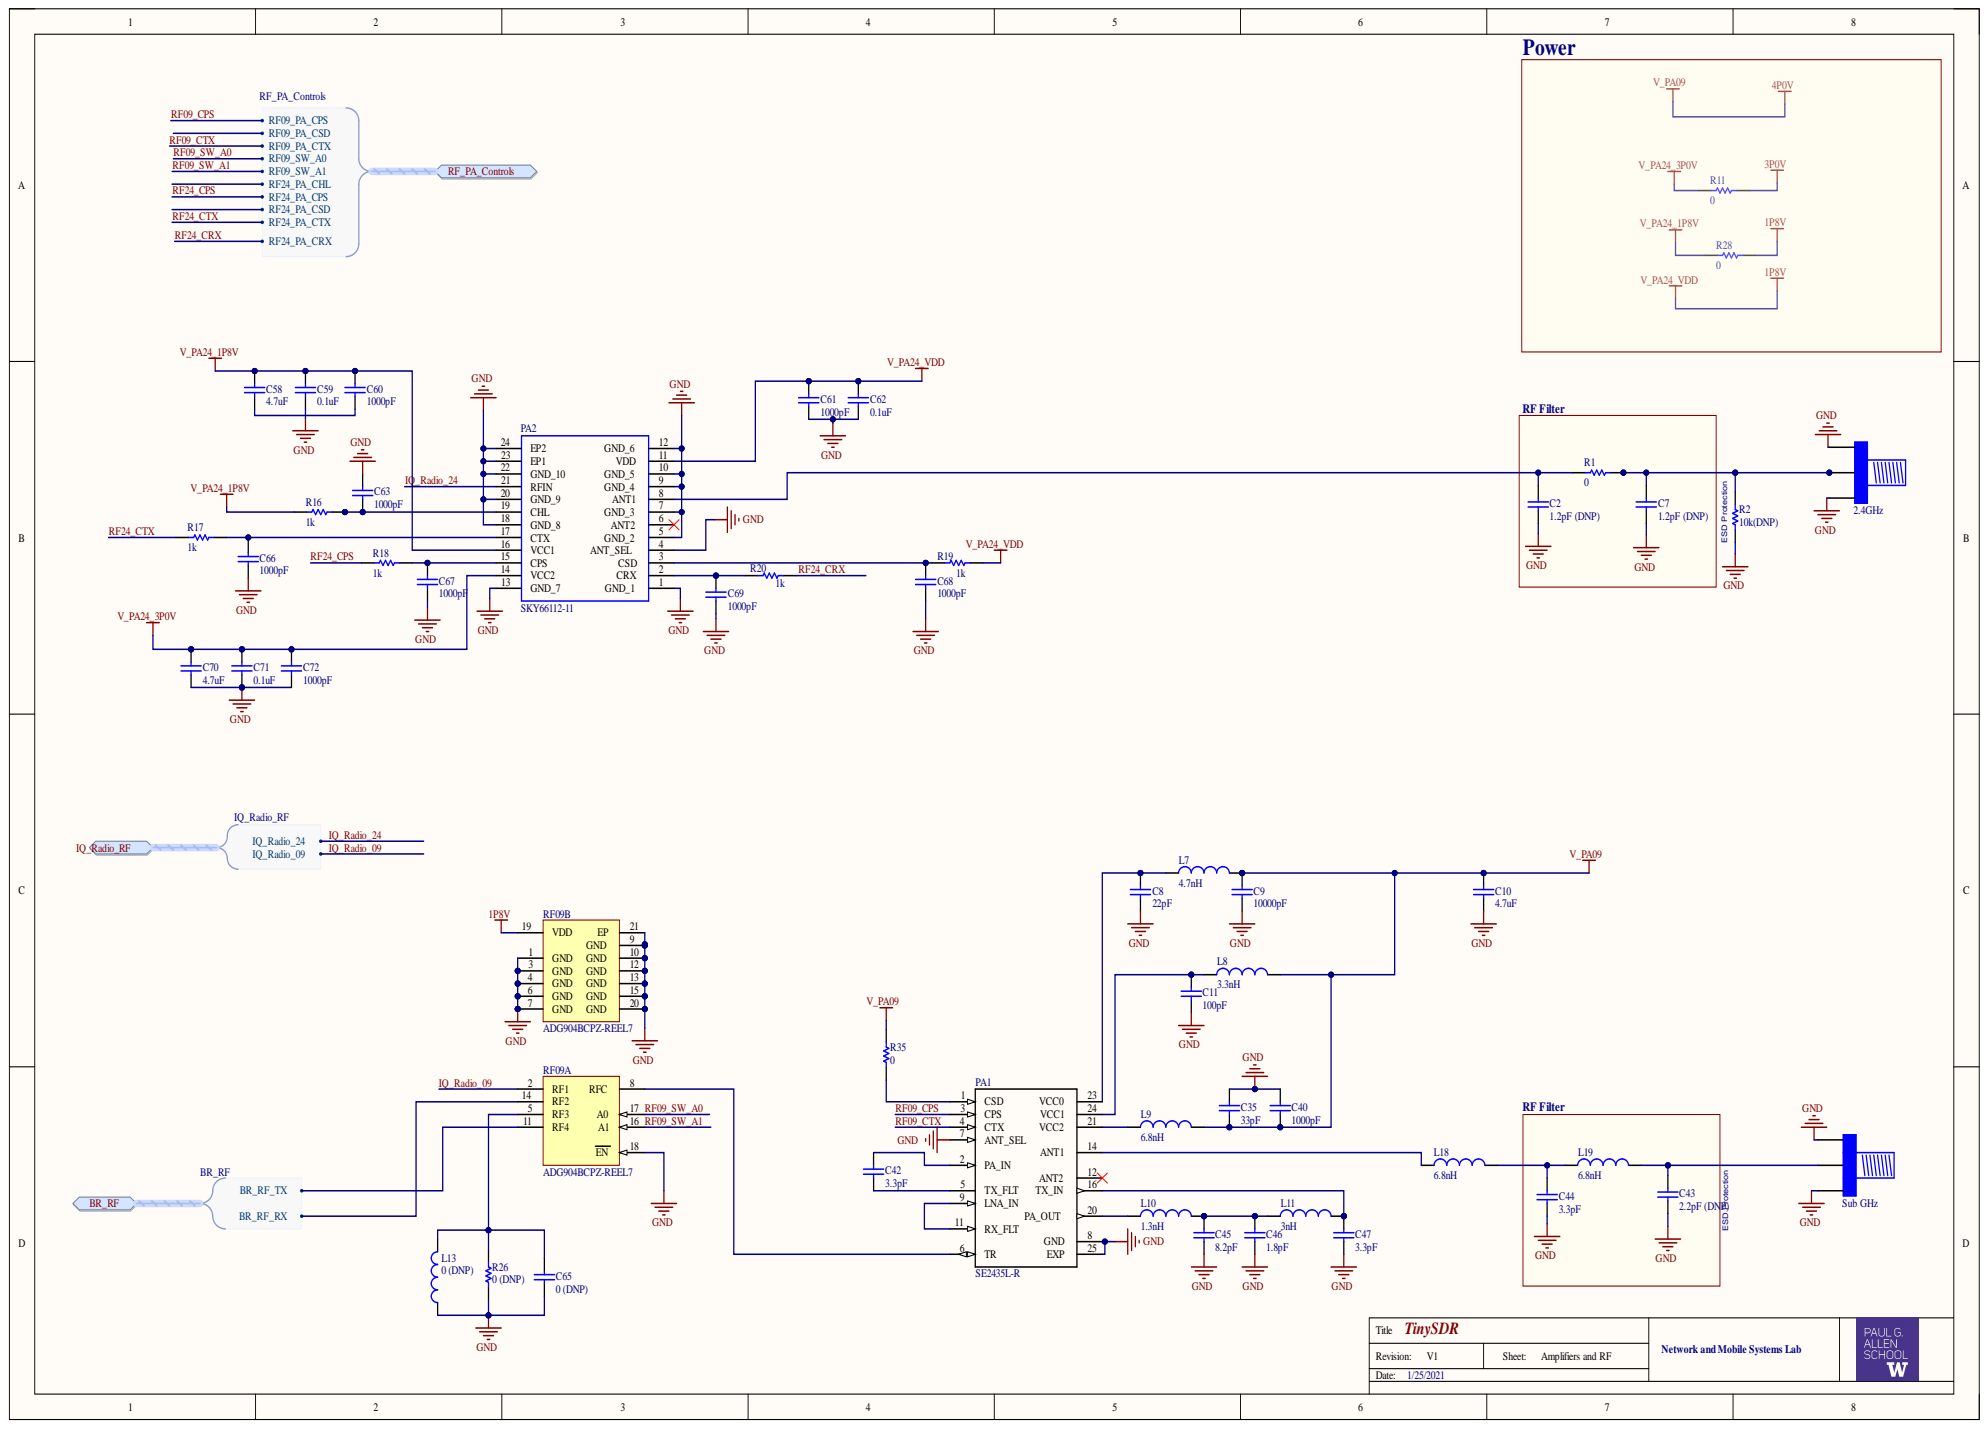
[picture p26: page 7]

LNA_IN 9 TX_FLT 5 | | L10 L11

RX_FLT 11

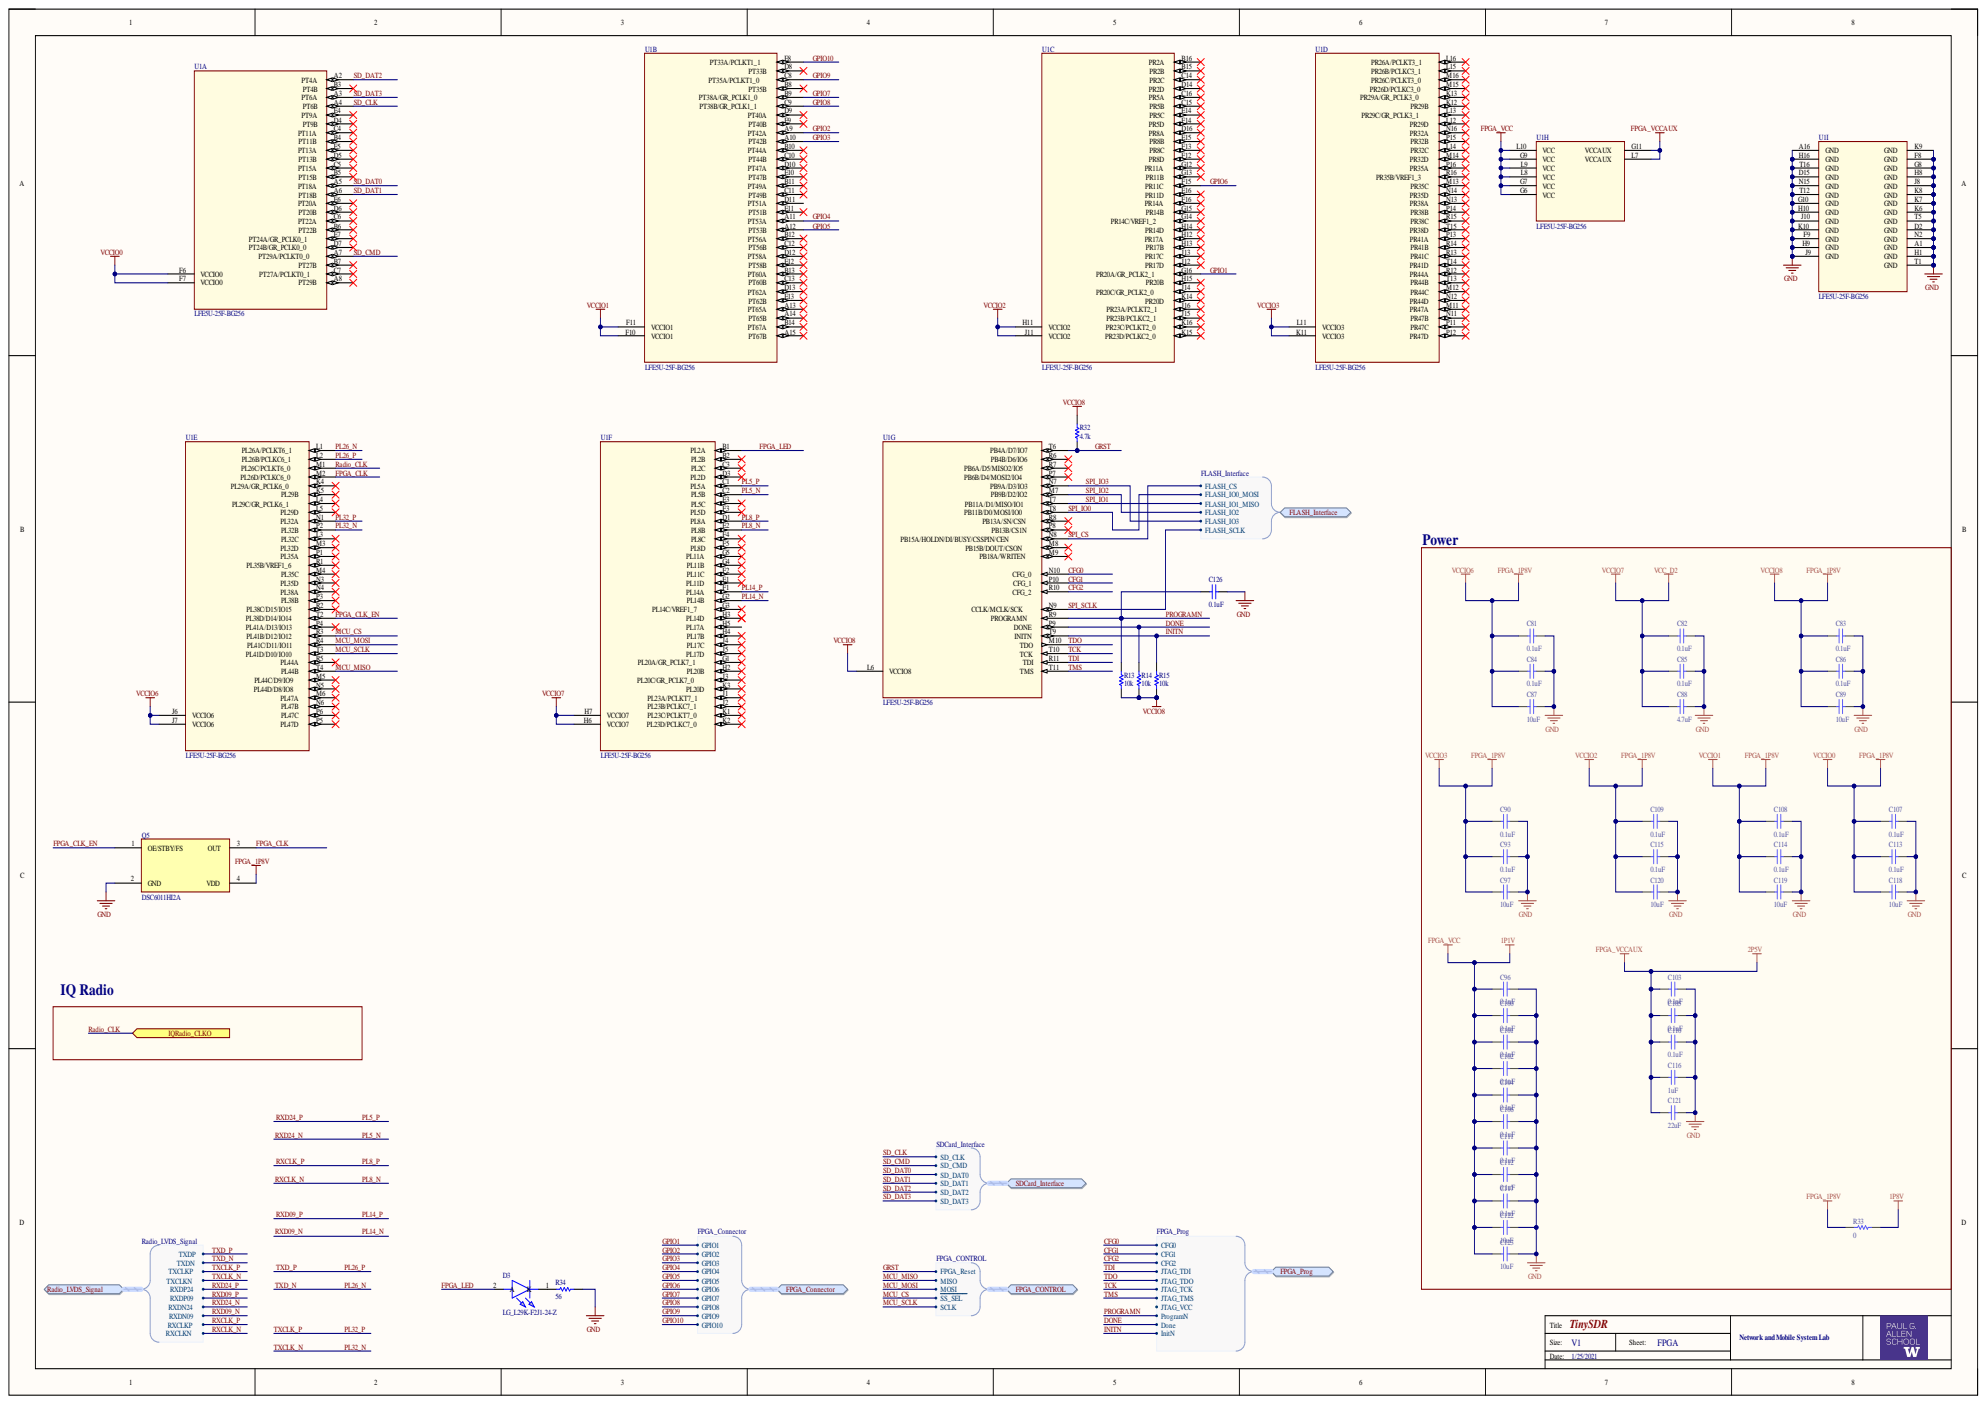
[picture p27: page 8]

SPI_IO1

SPI_CS

TinySDR Title | Network andMobile System Lab
V1 Size: | Sheet: FPGA

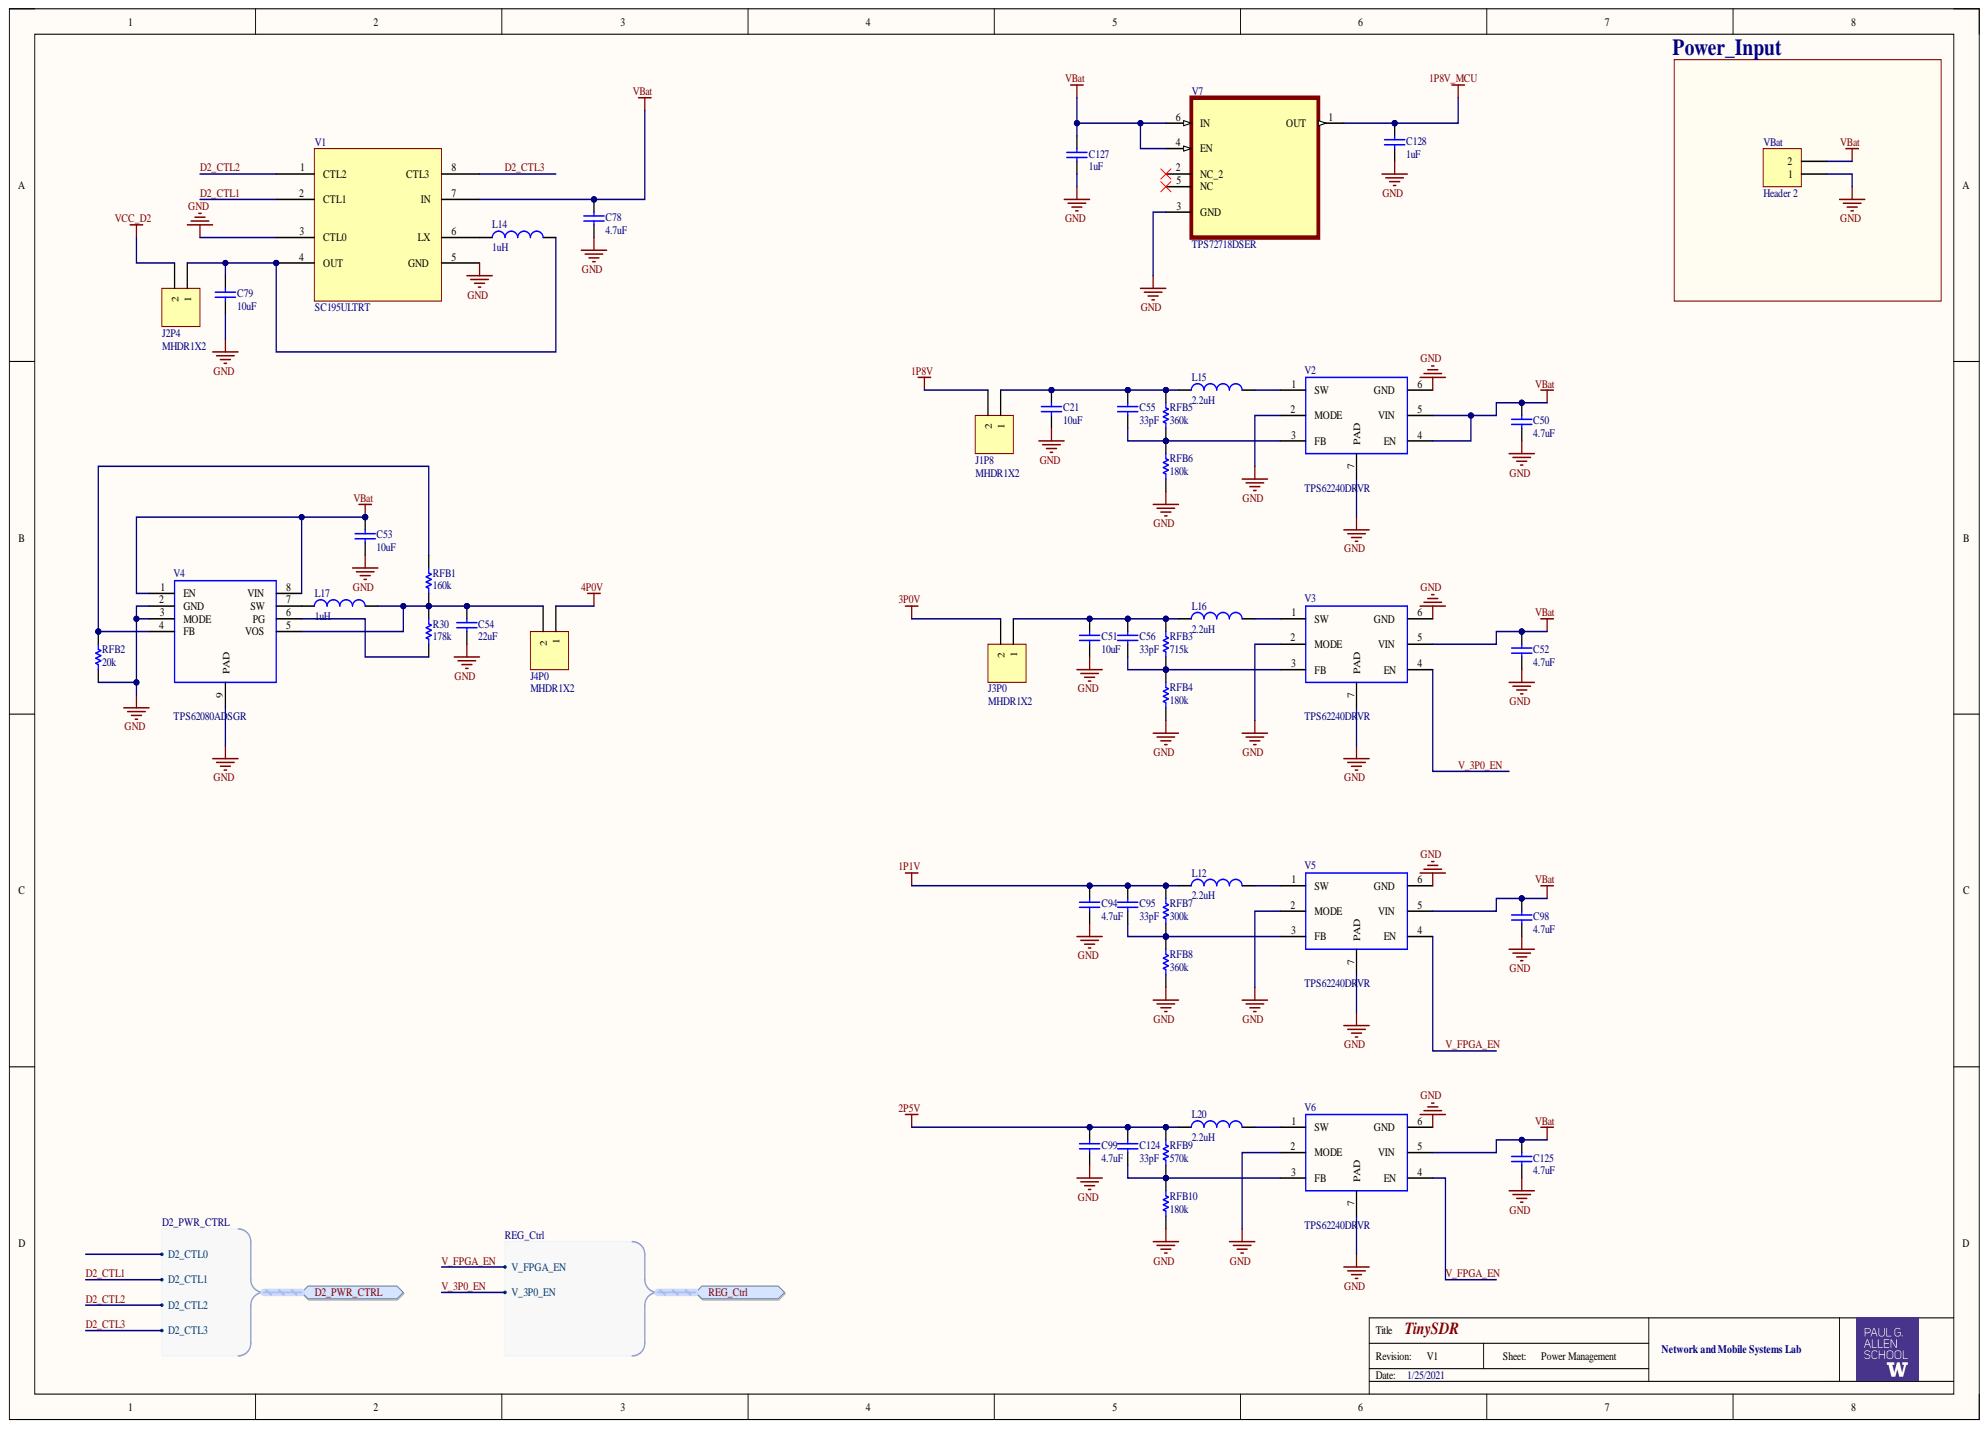
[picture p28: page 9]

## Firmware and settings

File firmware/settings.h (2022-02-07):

/*
 _____  _                _____ ______ ______
|_   _|(_)              /  ___||  _  \| ___ \
  | |   _  _ __   _   _ \ `--. | | | || |_/ /
  | |  | || '_ \ | | | | `--. \| | | ||    /
  | |  | || | | || |_| |/\__/ /| |/ / | |\ \
  \_/  |_||_| |_| \__, |\____/ |___/  \_| \_|
                   __/ |
                  |___/
Description: TinySDR Settings

License: see LICENSE.TXT file include in the project

Maintainer: Mehrdad Hessar, Ali Najafi
*/
#ifndef _SETTINGS_H_
#define _SETTINGS_H_
#include <libraries/gpio.h>


/* Structure for the MSP pins */
typedef struct {
    volatile uint8_t*   portOut;
    volatile uint8_t*   portIn;
    volatile uint8_t*   portDir;
    uint8_t             pin;
    uint8_t             portNumber;
} MSP_PIN_t;

/**#############################Debug#############################**/
//#define DEBUG

/**#############################Platform#############################**/
#define PLATFORM_TINYSDR		1
//#define PLATFORM_REB215			2
//#define PLATFORM			platform_tinySDR



/**#############################CONFIGURATION#############################**/
/* Pin definition based on the board design */
const static MSP_PIN_t PIN_MSP_P1_0		= {P1_0, 0x01};
const static MSP_PIN_t PIN_MSP_P1_1		= {P1_1, 0x01};
const static MSP_PIN_t PIN_MSP_P1_2     = {P1_2, 0x01};
const static MSP_PIN_t PIN_MSP_P1_3     = {P1_3, 0x01};
const static MSP_PIN_t PIN_MSP_P1_4		= {P1_4, 0x01};
const static MSP_PIN_t PIN_MSP_P1_5     = {P1_5, 0x01};
const static MSP_PIN_t PIN_MSP_P1_6     = {P1_6, 0x01};
const static MSP_PIN_t PIN_MSP_P1_7     = {P1_7, 0x01};

const static MSP_PIN_t PIN_MSP_P2_0		= {P2_0, 0x02};
const static MSP_PIN_t PIN_MSP_P2_1		= {P2_1, 0x02};
const static MSP_PIN_t PIN_MSP_P2_2		= {P2_2, 0x02};
const static MSP_PIN_t PIN_MSP_P2_3		= {P2_3, 0x02};
const static MSP_PIN_t PIN_MSP_P2_4		= {P2_4, 0x02};
const static MSP_PIN_t PIN_MSP_P2_5		= {P2_5, 0x02};
const static MSP_PIN_t PIN_MSP_P2_6		= {P2_6, 0x02};
const static MSP_PIN_t PIN_MSP_P2_7		= {P2_7, 0x02};


const static MSP_PIN_t PIN_MSP_P3_0		= {P3_0, 0x03};
const static MSP_PIN_t PIN_MSP_P3_1		= {P3_1, 0x03};
const static MSP_PIN_t PIN_MSP_P3_2		= {P3_2, 0x03};
const static MSP_PIN_t PIN_MSP_P3_3		= {P3_3, 0x03};
const static MSP_PIN_t PIN_MSP_P3_4     = {P3_4, 0x03};
const static MSP_PIN_t PIN_MSP_P3_5     = {P3_5, 0x03};
const static MSP_PIN_t PIN_MSP_P3_6     = {P3_6, 0x03};
const static MSP_PIN_t PIN_MSP_P3_7		= {P3_7, 0x03};


const static MSP_PIN_t PIN_MSP_P4_0		= {P4_0, 0x04};
const static MSP_PIN_t PIN_MSP_P4_1		= {P4_1, 0x04};
const static MSP_PIN_t PIN_MSP_P4_2		= {P4_2, 0x04};
const static MSP_PIN_t PIN_MSP_P4_3		= {P4_3, 0x04};
const static MSP_PIN_t PIN_MSP_P4_4		= {P4_4, 0x04};
const static MSP_PIN_t PIN_MSP_P4_5		= {P4_5, 0x04};
const static MSP_PIN_t PIN_MSP_P4_6		= {P4_6, 0x04};
const static MSP_PIN_t PIN_MSP_P4_7		= {P4_7, 0x04};


const static MSP_PIN_t PIN_MSP_P5_0     = {P5_0, 0x05};
const static MSP_PIN_t PIN_MSP_P5_1     = {P5_1, 0x05};
const static MSP_PIN_t PIN_MSP_P5_2     = {P5_2, 0x05};
const static MSP_PIN_t PIN_MSP_P5_3     = {P5_3, 0x05};
const static MSP_PIN_t PIN_MSP_P5_4     = {P5_4, 0x05};
const static MSP_PIN_t PIN_MSP_P5_5     = {P5_5, 0x05};
const static MSP_PIN_t PIN_MSP_P5_6     = {P5_6, 0x05};
const static MSP_PIN_t PIN_MSP_P5_7     = {P5_7, 0x05};

const static MSP_PIN_t PIN_MSP_P6_0		= {P6_0, 0x06};
const static MSP_PIN_t PIN_MSP_P6_1		= {P6_1, 0x06};
const static MSP_PIN_t PIN_MSP_P6_2		= {P6_2, 0x06};
const static MSP_PIN_t PIN_MSP_P6_3		= {P6_3, 0x06};
const static MSP_PIN_t PIN_MSP_P6_4		= {P6_4, 0x06};
const static MSP_PIN_t PIN_MSP_P6_5		= {P6_5, 0x06};
const static MSP_PIN_t PIN_MSP_P6_6		= {P6_6, 0x06};
const static MSP_PIN_t PIN_MSP_P6_7		= {P6_7, 0x06};

const static MSP_PIN_t PIN_MSP_P7_0		= {P7_0, 0x07};
const static MSP_PIN_t PIN_MSP_P7_1		= {P7_1, 0x07};
const static MSP_PIN_t PIN_MSP_P7_2		= {P7_2, 0x07};
const static MSP_PIN_t PIN_MSP_P7_3		= {P7_3, 0x07};
const static MSP_PIN_t PIN_MSP_P7_4		= {P7_4, 0x07};
const static MSP_PIN_t PIN_MSP_P7_5		= {P7_5, 0x07};
const static MSP_PIN_t PIN_MSP_P7_6		= {P7_6, 0x07};
const static MSP_PIN_t PIN_MSP_P7_7		= {P7_7, 0x07};

const static MSP_PIN_t PIN_MSP_P8_0		= {P8_0, 0x08};
const static MSP_PIN_t PIN_MSP_P8_1		= {P8_1, 0x08};
const static MSP_PIN_t PIN_MSP_P8_2		= {P8_2, 0x08};

const static MSP_PIN_t PIN_MSP_PJ_0		= {PJ_0, 0x0B};
const static MSP_PIN_t PIN_MSP_PJ_1		= {PJ_1, 0x0B};
const static MSP_PIN_t PIN_MSP_PJ_2		= {PJ_2, 0x0B};
const static MSP_PIN_t PIN_MSP_PJ_3		= {PJ_3, 0x0B};
const static MSP_PIN_t PIN_MSP_PJ_4		= {PJ_4, 0x0B};
const static MSP_PIN_t PIN_MSP_PJ_5		= {PJ_5, 0x0B};
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

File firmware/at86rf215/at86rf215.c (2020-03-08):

/*
 _____  _                _____ ______ ______
|_   _|(_)              /  ___||  _  \| ___ \
  | |   _  _ __   _   _ \ `--. | | | || |_/ /
  | |  | || '_ \ | | | | `--. \| | | ||    /
  | |  | || | | || |_| |/\__/ /| |/ / | |\ \
  \_/  |_||_| |_| \__, |\____/ |___/  \_| \_|
                   __/ |
                  |___/
Description: Generic AT86RF215 driver implementation

License: see LICENSE.TXT file include in the project

Maintainers:	Mehrdad Hessar, Ali Najafi
*/
#include <at86rf215/at86rf215.h>
#include <libraries/board.h>
#include <math.h>
#include <string.h>


/**########################Variables and Types############################**/
static RadioEvents_t *RadioEvents;
AT86RF215_t AT86RF215;

/**########################Internal functions############################**/
void bitSet(uint8_t *value, uint8_t bit);
void bitClear(uint8_t *value, uint8_t bit);
void bitWrite(uint16_t addr, uint8_t pos, uint8_t newValue);
uint8_t bitRead(uint16_t addr, uint8_t pos);
void AT86RF215ReadFifo( uint8_t *buffer, uint8_t size );
void AT86RF215SetOpMode( uint8_t opMode );

void AT86RF215SetLVDSCMV(bool v1_2, uint8_t cmv);
void AT86RF215SetIRQMask(bool status, uint8_t pos);
void AT86RF215SetIQSkewDrive(uint8_t skew);
void AT86RF215SetIQCurrentDrive(uint8_t drive);
void AT86RF215AGCSetTGT(uint8_t tgt);
void AT86RF215AGCSetAGCC(bool agci, uint8_t agc_average);

/**########################External functions############################**/
void AT86RF215Init(RadioEvents_t *events)
{
    RadioEvents = events;
    AT86RF215Reset();
    AT86RF215.RF_Settings.channelComplient = false;
}


At86rf215_RadioState_t AT86RF215GetStatus(void)
{
	//TODO:
	At86rf215_RadioState_t test = RF_TRXOFF;
    return test;
}

void AT86RF215SetModem(At86rf215_RadioModems_t modem)
{
    AT86RF215.RF_Settings.Modem = modem;
}

void AT86RF215RxSetIFS(uint8_t IFS)
{
	if (AT86RF215.RF_Settings.Modem == MODEM_09){
		bitWrite(REG_RF09_RXBWC, 4, IFS);
	} else if (AT86RF215.RF_Settings.Modem == MODEM_24){
		bitWrite(REG_RF24_RXBWC, 4, IFS);
	}
	else{
		PrintError(ERROR_Modem);
	}
}

void AT86RF215SetTXCI(uint8_t txci)
{
	txci &= 0x3F;
	AT86RF215Write(REG_RF09_TXCI, txci);
}

void AT86RF215SetTXCQ(uint8_t txcq)
{
	txcq &= 0x3F;
	AT86RF215Write(REG_RF09_TXCQ, txcq);
}


void AT86RF215SetChannel( uint32_t freq )
{
//    uint8_t RFn_CS;
    uint8_t RFn_CCF0H;
    uint8_t RFn_CCF0L;
    uint8_t RFn_CNL;
    uint8_t RFn_CNM;
    double temp;

    AT86RF215.RF_Settings.Channel = freq;

	if ((freq <= 510000000) && (freq >= 389500000))
	{
		freq = freq - 377000000;

		freq =      (uint32_t) ((double)freq / (double)FREQ_STEP1);
		RFn_CCF0H =   (uint8_t)  ((freq >> 16) & 0xFF);
		RFn_CCF0L = (uint8_t)  ((freq >> 8) & 0xFF);
		RFn_CNL =   (uint8_t)  (freq & 0xFF);
		RFn_CNM = 0x40;
	}
	else if ((freq >= 779000000) && (freq <= 1020000000))
	{
		freq = freq - 754000000;
		temp =  (double) (freq);
		temp = (temp * 65536) / 13000000;
		freq = (uint32_t) temp;

//		freq =      (uint32_t) ((double)freq / (double)FREQ_STEP2);
//		freq =      (uint32_t) (((long)freq * (long)(65536)) / long(13000000));

		RFn_CCF0H =   (uint8_t)  ((freq >> 16) & 0xFF);
//        printf("reg value: %x \n", RFn_CCF0H);

		RFn_CCF0L = (uint8_t)  ((freq >> 8) & 0xFF);//25KHz off, so we added 25KHz to compensate for that
//		printf("reg value: %x \n", RFn_CCF0L);

		RFn_CNL =   (uint8_t)  (freq & 0xFF);
//		printf("reg value: %x \n", RFn_CNL);
		RFn_CNM = 0x80;

		/* set REG_RFn_CCF0L */
		AT86RF215Write(REG_RF09_CCF0L, RFn_CCF0L);

		/* set REG_RFn_CCF0H */
		AT86RF215Write(REG_RF09_CCF0H, RFn_CCF0H);

		/* set REG_RFn_CNL */
		AT86RF215Write(REG_RF09_CNL, RFn_CNL);

		/* set REG_RFn_CNM */
		AT86RF215Write(REG_RF09_CNM, RFn_CNM);

	}
	else if ((freq >= 2400000000) && (freq <= 2483500000))
	{
		freq = freq - 2366000000;
		freq =      (uint32_t) ((double)freq / (double)FREQ_STEP3);
		RFn_CCF0H =   (uint8_t)  ((freq >> 16) & 0xFF);
		RFn_CCF0L = (uint8_t)  ((freq >> 8) & 0xFF);
		RFn_CNL =   (uint8_t)  (freq & 0xFF);
		RFn_CNM = 0xC0;

		AT86RF215Write(REG_RF24_CCF0L, RFn_CCF0L);
		AT86RF215Write(REG_RF24_CCF0H, RFn_CCF0H);
		AT86RF215Write(REG_RF24_CNL, RFn_CNL);
		AT86RF215Write(REG_RF24_CNM, RFn_CNM);
	}
	else
	{
//            TODO
		PrintError(ERROR_Frequency);
	}

}

bool AT86RF215IsChannelFree( At86rf215_RadioModems_t modem, uint32_t freq, int16_t rssiThresh )
{
	//TODO
    return 0;
}

uint32_t AT86RF215Random( void )
{
	//TODO
	return  0;
}

void AT86RF215RxSetConfig( At86rf215_RadioModems_t modem, uint32_t bandwidth,
                         uint32_t datarate, uint8_t coderate,
                         uint32_t bandwidthAfc, uint16_t preambleLen,
                         uint16_t symbTimeout, bool fixLen,
                         uint8_t payloadLen,
                         bool crcOn, bool FreqHopOn, uint8_t HopPeriod,
                         bool iqInverted, bool rxContinuous )
{
	//TODO
}

void AT86RF215TxSetConfig( At86rf215_RadioModems_t modem, int8_t power, uint32_t fdev,
                        uint32_t bandwidth, uint32_t datarate,
                        uint8_t coderate, uint16_t preambleLen,
                        bool fixLen, bool crcOn, bool FreqHopOn,
                        uint8_t HopPeriod, bool iqInverted, uint32_t timeout )
{
	//TODO
}

uint32_t AT86RF215GetTimeOnAir( At86rf215_RadioModems_t modem, uint8_t pktLen )
{
	//TODO
    return 0;
}

void AT86RF215Send( uint8_t *buffer, uint8_t size )
{
	//TODO
}

void AT86RF215SetSleep( void )
{
	//TODO
}

void AT86RF215SetStby( void )
{
	//TODO
}

void AT86RF215RxSet( uint32_t timeout )
{
	//TODO
}

void AT86RF215StartCad( void )
{
	//TODO
}

int16_t AT86RF215ReadRssi( At86rf215_RadioModems_t modem )
{
	//TODO
	return 0;
}

void AT86RF215Write( uint16_t addr, uint8_t data )
{
    AT86RF215WriteBuffer( addr, &data, 1 );
}

uint8_t AT86RF215Read( uint16_t addr )
{
    uint8_t data;
    /* SPI reads previous byte */
    AT86RF215ReadBuffer(addr, &data, 1);
    return data;
}


void AT86RF215WriteBuffer( uint16_t addr, uint8_t *buffer, uint8_t size )
{
    uint8_t i;

    uint8_t addr0 = ((addr >> 8) & 0x3F) | 0x80;
    uint8_t addr1 = addr & 0xFF;

    GpioWrite( &AT86RF215.Spi.NSS, 0 );

    SpiInOut_IQRadio(&AT86RF215.Spi, addr0);
    SpiInOut_IQRadio(&AT86RF215.Spi, addr1);

    for( i = 0; i < size; i++ )
    {
    	SpiInOut_IQRadio( &AT86RF215.Spi, buffer[i]);
    }

    GpioWrite( &AT86RF215.Spi.NSS, 1 );
}

void AT86RF215ReadBuffer(uint16_t addr, uint8_t *buffer, uint8_t size)
{
    uint8_t i;
    uint8_t addr0 = (addr >> 8) & 0x3F;
    uint8_t addr1 = addr & 0xFF;

    GpioWrite(&AT86RF215.Spi.NSS, 0);

    SpiInOut_IQRadio(&AT86RF215.Spi, addr0);
    SpiInOut_IQRadio(&AT86RF215.Spi, addr1);

    for( i = 0; i < size; i++ )
    {
        buffer[i] = SpiInOut_IQRadio(&AT86RF215.Spi, 0);
    }

    GpioWrite(&AT86RF215.Spi.NSS, 1);
}

void AT86RF215SetMaxPayloadLength( At86rf215_RadioModems_t modem, uint8_t max )
{
	//TODO
}
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

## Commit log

2019-06-11 hardware schematic added
2020-03-08 updated schematic
2021-01-17 pcb layout added
2022-02-07 ported PCB layout to KiCad6 so I can open it
    [CLT01-38SQ7-TR.stp, LED 0603 single color.stp, MSP432P401RIRGCR.stp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]
2022-02-07 project can now build in CCS11. See commit description.
    In this commit:
    - Not sure what version of CCS the project was originally built in, but it took lots of include path tweaking to get this project to build.
    - fixed some invalid code in main.c
    - commented out all references of testmini.h -- what is testmini.h??
    - changed the build commands to use system default rather than hard coded
    - added `FlashWriteBin` function to mx25r6425f.c that writes binary files from PC to SPI flash chip
    - temporarily changed `FlashMassCheck` to write flash contents to binary file on PC.
    - added GPIO definitions for FPGA PROGRAMn, DONE, and INITn pins. They're under TinySDR.FPGA
    - changed debugger to use a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
    [board.c, mx25r6435f.c, settings.h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]
